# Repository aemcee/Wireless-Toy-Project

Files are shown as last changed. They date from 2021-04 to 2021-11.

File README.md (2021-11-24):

# Wireless-Toy-Project
ATmega328P based custom remote and unit (receiver) boards on arduino framework that will communicate over RF and with the following feature set: SD Card, RTC, Ultrasonic sensor, motor control, audio amplification w/audio jack or 8ohm speaker, motor control, LEDs

Remote PCB will replace current board in toy remote housing and receiver board will have custom 3D printed housing

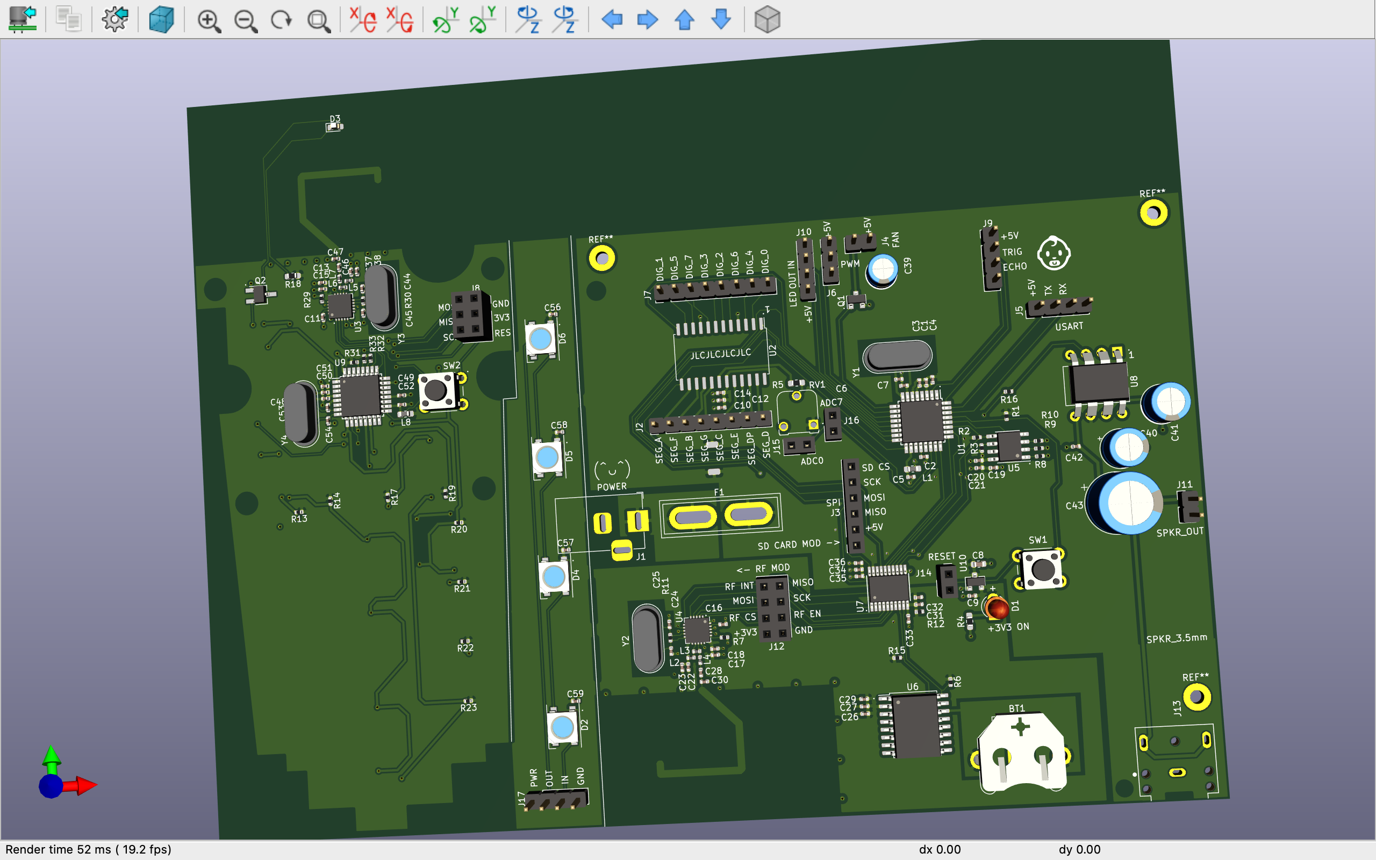
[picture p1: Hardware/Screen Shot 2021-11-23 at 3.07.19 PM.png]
name-of-you-image


Watch the video (https://youtu.be/jzv-52mN5sE)

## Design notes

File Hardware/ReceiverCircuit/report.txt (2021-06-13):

Info: Checking netlist symbol footprint “L1:/5F267CB6/5F404F19:Inductor_SMD:L_0603_1608Metric_Pad1.05x0.95mm_HandSolder”.
Info: Checking netlist symbol footprint “R4:/5F267E17/5F47181E:Resistor_SMD:R_0402_1005Metric”.
Info: Checking netlist symbol footprint “R3:/5F267CB6/5F282A2E:Resistor_SMD:R_0402_1005Metric”.
Info: Checking netlist symbol footprint “R2:/5F267CB6/5F283506:Resistor_SMD:R_0402_1005Metric”.
Info: Checking netlist symbol footprint “R1:/5F267CB6/5F312DFC:Resistor_SMD:R_0402_1005Metric”.
Info: Checking netlist symbol footprint “Q1:/5F26E841/5F41FD7E:Package_TO_SOT_SMD:SOT-23”.
Info: Checking netlist symbol footprint “L4:/5F26E841/5F33637F:Inductor_SMD:L_0402_1005Metric”.
Info: Checking netlist symbol footprint “L3:/5F26E841/5F33480A:Inductor_SMD:L_0402_1005Metric”.
Info: Checking netlist symbol footprint “L2:/5F26E841/5F337A25:Inductor_SMD:L_0402_1005Metric”.
Info: Checking netlist symbol footprint “R5:/5F26E841/5F3EAB85:Resistor_SMD:R_0603_1608Metric_Pad1.05x0.95mm_HandSolder”.
Info: Checking netlist symbol footprint “J7:/5F26E841/5F3A1FBF:Connector_PinHeader_2.54mm:PinHeader_1x04_P2.54mm_Vertical”.
Info: Checking netlist symbol footprint “J6:/5F30B967/5F3D61E1:Connector_PinHeader_2.54mm:PinHeader_1x03_P2.54mm_Vertical”.
Info: Checking netlist symbol footprint “J5:/5F30B967/5F3E867E:Connector_PinHeader_2.54mm:PinHeader_1x04_P2.54mm_Vertical”.
Info: Checking netlist symbol footprint “J4:/5F30B967/5F421C06:Connector_PinHeader_2.54mm:PinHeader_1x02_P2.54mm_Vertical”.
Info: Checking netlist symbol footprint “J3:/5F30B967/5F30DA44:Connector_PinHeader_2.54mm:PinHeader_1x03_P2.54mm_Vertical”.
Info: Checking netlist symbol footprint “J2:/5F30B967/5F30E60B:Connector_PinHeader_2.54mm:PinHeader_2x03_P2.54mm_Vertical”.
Info: Checking netlist symbol footprint “J1:/5F267E17/5F3750C2:Connector_BarrelJack:BarrelJack_Horizontal”.
Info: Checking netlist symbol footprint “F1:/5F267E17/5F26B922:Fuse:Fuse_Blade_ATO_directSolder”.
Info: Checking netlist symbol footprint “U1:/5F267CB6/5F27CF0E:Package_QFP:TQFP-32_7x7mm_P0.8mm”.
Info: Checking netlist symbol footprint “Y2:/5F26E841/5F3117DC:Crystal:Crystal_HC49-4H_Vertical”.
Info: Checking netlist symbol footprint “Y1:/5F267CB6/5F37F7A6:Crystal:Crystal_HC49-4H_Vertical”.
Info: Checking netlist symbol footprint “U10:/5F267E17/5F43C6FB:Package_TO_SOT_SMD:SOT-23”.
Info: Checking netlist symbol footprint “U7:/5F27C6CE/5F2CA946:Package_SO:TSSOP-20_4.4x6.5mm_P0.65mm”.
Info: Checking netlist symbol footprint “U6:/5F26E841/5F27713A:Package_SO:SOIC-16W_7.5x10.3mm_P1.27mm”.
Info: Checking netlist symbol footprint “U5:/5F26E841/5F26F784:Package_SO:SOIC-8_3.9x4.9mm_P1.27mm”.
Info: Checking netlist symbol footprint “U4:/5F26E841/5F279D2C:Package_DFN_QFN:QFN-20-1EP_4x4mm_P0.5mm_EP2.5x2.5mm”.
Info: Checking netlist symbol footprint “U2:/5F26E841/5F274BCB:Package_SO:SOP-24_7.5x15.4mm_P1.27mm”.
Info: Checking netlist symbol footprint “BT1:/5F26E841/5F2F7BE9:Battery:BatteryHolder_Keystone_3001_1x12mm”.
Info: Checking netlist symbol footprint “SW1:/5F267CB6/5F3116D4:Button_Switch_THT:SW_PUSH_6mm_H5mm”.
Info: Checking netlist symbol footprint “R12:/5F27C6CE/5F2F0D13:Resistor_SMD:R_0402_1005Metric”.
Info: Checking netlist symbol footprint “R11:/5F26E841/5F3167C4:Resistor_SMD:R_0402_1005Metric”.
Info: Checking netlist symbol footprint “R10:/5F26E841/5F261A38:Resistor_SMD:R_0402_1005Metric”.
Info: Checking netlist symbol footprint “R9:/5F26E841/5F262E96:Resistor_SMD:R_0402_1005Metric”.
Info: Checking netlist symbol footprint “R8:/5F26E841/5F263156:Resistor_SMD:R_0402_1005Metric”.
Info: Checking netlist symbol footprint “R7:/5F26E841/5F308377:Resistor_SMD:R_0402_1005Metric”.
Info: Checking netlist symbol footprint “R6:/5F27C6CE/5F3A68C5:Resistor_SMD:R_0402_1005Metric”.
Info: Checking netlist symbol footprint “C10:/5F26E841/5F3E017E:Capacitor_SMD:C_0402_1005Metric”.
Info: Checking netlist symbol footprint “C22:/5F26E841/5F3464D5:Capacitor_SMD:C_0402_1005Metric”.
Info: Checking netlist symbol footprint “C21:/5F26E841/5F28EC82:Capacitor_SMD:C_0402_1005Metric”.
Info: Checking netlist symbol footprint “C20:/5F26E841/5F28EC7B:Capacitor_SMD:C_0402_1005Metric”.
Info: Checking netlist symbol footprint “C19:/5F26E841/5F28EC74:Capacitor_SMD:C_0402_1005Metric”.
Info: Checking netlist symbol footprint “C18:/5F26E841/5F3017C4:Capacitor_SMD:C_0402_1005Metric”.
Info: Checking netlist symbol footprint “C17:/5F26E841/5F3017BD:Capacitor_SMD:C_0402_1005Metric”.
Info: Checking netlist symbol footprint “C16:/5F26E841/5F3AC90D:Capacitor_SMD:C_0402_1005Metric”.
Info: Checking netlist symbol footprint “C14:/5F26E841/5F3E018C:Capacitor_SMD:C_0402_1005Metric”.
Info: Checking netlist symbol footprint “C12:/5F26E841/5F3E0185:Capacitor_SMD:C_0402_1005Metric”.
Info: Checking netlist symbol footprint “D1:/5F267E17/5F470E62:”.
Info: Checking netlist symbol footprint “C9:/5F267E17/5F26B8F5:Capacitor_SMD:C_0402_1005Metric”.
Info: Checking netlist symbol footprint “C8:/5F267E17/5F26B8EF:Capacitor_SMD:C_0603_1608Metric”.
Info: Checking netlist symbol footprint “C7:/5F267CB6/5F381AE7:Capacitor_SMD:C_0402_1005Metric”.
Info: Checking netlist symbol footprint “C6:/5F267CB6/5F380939:Capacitor_SMD:C_0402_1005Metric”.
Info: Checking netlist symbol footprint “C5:/5F267CB6/5F40669F:Capacitor_SMD:C_0402_1005Metric”.
Info: Checking netlist symbol footprint “C4:/5F267CB6/5F27AAE0:Capacitor_SMD:C_0402_1005Metric”.
Info: Checking netlist symbol footprint “C3:/5F267CB6/5F27A7B7:Capacitor_SMD:C_0402_1005Metric”.
Info: Checking netlist symbol footprint “C2:/5F267CB6/5F314F9A:Capacitor_SMD:C_0402_1005Metric”.
Info: Checking netlist symbol footprint “C1:/5F267CB6/5F279DA3:Capacitor_SMD:C_0402_1005Metric”.
Info: Checking netlist symbol footprint “C24:/5F26E841/5F3199E1:Capacitor_SMD:C_0402_1005Metric”.
Info: Checking netlist symbol footprint “C36:/5F27C6CE/5F2CE47A:Capacitor_SMD:C_0402_1005Metric”.
Info: Checking netlist symbol footprint “C35:/5F27C6CE/5F2CE473:Capacitor_SMD:C_0402_1005Metric”.
Info: Checking netlist symbol footprint “C34:/5F27C6CE/5F2CE46C:Capacitor_SMD:C_0402_1005Metric”.
Info: Checking netlist symbol footprint “C33:/5F27C6CE/5F2CF71E:Capacitor_SMD:C_0402_1005Metric”.
Info: Checking netlist symbol footprint “C32:/5F27C6CE/5F2CF717:Capacitor_SMD:C_0402_1005Metric”.
Info: Checking netlist symbol footprint “C31:/5F27C6CE/5F2CF710:Capacitor_SMD:C_0402_1005Metric”.
Info: Checking netlist symbol footprint “C30:/5F26E841/5F340567:Capacitor_SMD:C_0402_1005Metric”.
Info: Checking netlist symbol footprint “C29:/5F26E841/5F2BBA88:Capacitor_SMD:C_0402_1005Metric”.
Info: Checking netlist symbol footprint “C28:/5F26E841/5F33F458:Capacitor_SMD:C_0402_1005Metric”.
Info: Checking netlist symbol footprint “C27:/5F26E841/5F2BBA81:Capacitor_SMD:C_0402_1005Metric”.
Info: Checking netlist symbol footprint “C26:/5F26E841/5F2BBA7A:Capacitor_SMD:C_0402_1005Metric”.
Info: Checking netlist symbol footprint “C25:/5F26E841/5F31BDA0:Capacitor_SMD:C_0402_1005Metric”.
Info: Checking netlist symbol footprint “C23:/5F26E841/5F3464DB:Capacitor_SMD:C_0402_1005Metric”.
Adding new symbol R10 footprint Resistor_SMD:R_0402_1005Metric.
Adding new symbol L2 footprint Inductor_SMD:L_0402_1005Metric.
Adding new symbol R9 footprint Resistor_SMD:R_0402_1005Metric.
Adding new symbol C30 footprint Capacitor_SMD:C_0402_1005Metric.
Adding new symbol R8 footprint Resistor_SMD:R_0402_1005Metric.
Adding new symbol L3 footprint Inductor_SMD:L_0402_1005Metric.
Adding new symbol L4 footprint Inductor_SMD:L_0402_1005Metric.
Adding new symbol Y1 footprint Crystal:Crystal_HC49-4H_Vertical.
Adding new symbol Y2 footprint Crystal:Crystal_HC49-4H_Vertical.
Error: Symbol J1 pad MP not found in footprint Connector_BarrelJack:BarrelJack_Horizontal.

Error: No footprint defined for symbol “D1”.

Error: Cannot add new symbol D1 due to missing footprint .

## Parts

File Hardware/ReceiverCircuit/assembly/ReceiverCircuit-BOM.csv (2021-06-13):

Comment | Designator | Footprint | LCSC
Battery_Cell | BT1 | Battery:BatteryHolder_Keystone_3001_1x12mm
.1u | C1,C2,C10,C19,C26,C31,C34,C42 | Capacitor_SMD:C_0402_1005Metric | C1525
33n | C16 | Capacitor_SMD:C_0402_1005Metric | C1585
10n | C17 | Capacitor_SMD:C_0402_1005Metric | C15195
1n | C18 | Capacitor_SMD:C_0402_1005Metric | C1523
2.2p | C22 | Capacitor_SMD:C_0402_1005Metric | C1559
4.7p | C23 | Capacitor_SMD:C_0402_1005Metric | C1569
1.5p | C28 | Capacitor_SMD:C_0402_1005Metric | C1552
.01u | C3,C12,C20,C27,C32,C35 | Capacitor_SMD:C_0402_1005Metric | C15195
1pF | C30 | Capacitor_SMD:C_0402_1005Metric | C1550
CP_Small | C39 | Capacitor_THT:CP_Radial_D5.0mm_P2.00mm
1u | C4,C9,C14,C21,C29,C33,C36 | Capacitor_SMD:C_0402_1005Metric | C52923
100u | C40,C41 | Capacitor_THT:CP_Radial_D6.3mm_P2.50mm
1000u | C43 | Capacitor_THT:CP_Radial_D10.0mm_P5.00mm
0.1u | C5 | Capacitor_SMD:C_0402_1005Metric | C1525
22p | C6,C7,C24,C25 | Capacitor_SMD:C_0402_1005Metric | C1555
10u | C8 | Capacitor_SMD:C_0603_1608Metric | C19702
LED_Small | D1 | LED_THT:LED_D3.0mm
2A | F1 | Fuse:Fuse_Blade_ATO_directSolder
Jack-DC | J1 | Connector_BarrelJack:BarrelJack_Horizontal
Conn_01x04_Male | J10 | Connector_PinHeader_2.54mm:PinHeader_1x04_P2.54mm_Vertical
Conn_02x04 | J12 | Connector_PinSocket_2.54mm:PinSocket_2x04_P2.54mm_Vertical
SJ1-3523N | J13 | ProjectFootprint:CUI_SJ1-3523N
Conn_01x02_Female | J14,J15,J16 | Connector_PinSocket_2.54mm:PinSocket_1x02_P2.54mm_Vertical
Conn_01x06_Female | J3 | Connector_PinSocket_2.54mm:PinSocket_1x06_P2.54mm_Vertical
Conn_01x02 | J4,J11 | Connector_PinHeader_2.54mm:PinHeader_1x02_P2.54mm_Vertical
Conn_01x04 | J5,J9 | Connector_PinHeader_2.54mm:PinHeader_1x04_P2.54mm_Vertical
Conn_01x03 | J6 | Connector_PinHeader_2.54mm:PinHeader_1x03_P2.54mm_Vertical
Conn_01x08 | J2,J7 | Connector_PinHeader_2.54mm:PinHeader_1x08_P2.54mm_Vertical
10u | L1 | Inductor_SMD:L_0603_1608Metric_Pad1.05x0.95mm_HandSolder
2.7n | L2 | Inductor_SMD:L_0402_1005Metric | C27123
8.2n | L3 | Inductor_SMD:L_0402_1005Metric | C16208
3.9n | L4 | Inductor_SMD:L_0402_1005Metric | C14033
Si2301CDS | Q1 | Package_TO_SOT_SMD:SOT-23 | C10487
10k | R1,R12 | Resistor_SMD:R_0402_1005Metric | C25744
1M | R11 | Resistor_SMD:R_0402_1005Metric | C26083
1k | R16 | Resistor_SMD:R_0402_1005Metric | C11702
4.7k | R2,R3,R6,R8,R9,R10,R15 | Resistor_SMD:R_0402_1005Metric | C25900
330 | R4 | Resistor_SMD:R_0603_1608Metric_Pad1.05x0.95mm_HandSolder
R_Small | R5 | Resistor_SMD:R_0603_1608Metric_Pad1.05x0.95mm_HandSolder
22k | R7 | Resistor_SMD:R_0402_1005Metric | C25768
R_POT_Small | RV1 | Potentiometer_THT:Potentiometer_Runtron_RM-065_Vertical
SW_Push | SW1 | Button_Switch_THT:SW_PUSH_6mm_H5mm
ATmega328P-AU | U1 | Package_QFP:TQFP-32_7x7mm_P0.8mm | C14877
TPS7A0533 | U10 | Package_TO_SOT_SMD:SOT-23
MAX7219 | U2 | Package_SO:SOP-24_7.5x15.4mm_P1.27mm
nRF24L01P | U4 | Package_DFN_QFN:QFN-20-1EP_4x4mm_P0.5mm_EP2.5x2.5mm | C8791
AT24C256C-SSHL-T | U5 | Package_SO:SOIC-8_3.9x4.9mm_P1.27mm | C6482
DS3231M | U6 | Package_SO:SOIC-16W_7.5x10.3mm_P1.27mm | C37663
TXS0108EPW | U7 | Package_SO:TSSOP-20_4.4x6.5mm_P0.65mm | C17206
LM386 | U8 | Package_DIP:DIP-8_W10.16mm
16MHz | Y1,Y2 | Crystal:Crystal_HC49-4H_Vertical

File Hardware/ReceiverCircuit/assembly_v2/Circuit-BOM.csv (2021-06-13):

Comment | Designator | Footprint | LCSC
Battery_Cell | BT1 | Battery:BatteryHolder_Keystone_3001_1x12mm
.1u | C1,C2,C10,C19,C26,C31,C34,C42,C48,C49 | Capacitor_SMD:C_0402_1005Metric | C1525
33n | C11,C16 | Capacitor_SMD:C_0402_1005Metric | C1585
10n | C13,C17 | Capacitor_SMD:C_0402_1005Metric | C15195
1n | C15,C18 | Capacitor_SMD:C_0402_1005Metric | C1523
2.2p | C22,C37 | Capacitor_SMD:C_0402_1005Metric | C1559
4.7p | C23,C38 | Capacitor_SMD:C_0402_1005Metric | C1569
1.5p | C28,C46 | Capacitor_SMD:C_0402_1005Metric | C1552
.01u | C3,C12,C20,C27,C32,C35,C50,C56,C57,C58,C59 | Capacitor_SMD:C_0402_1005Metric | C15195
1pF | C30,C47 | Capacitor_SMD:C_0402_1005Metric | C1550
CP_Small | C39 | Capacitor_THT:CP_Radial_D5.0mm_P2.00mm
1u | C4,C9,C14,C21,C29,C33,C36,C51 | Capacitor_SMD:C_0402_1005Metric | C52923
100u | C40,C41 | Capacitor_THT:CP_Radial_D6.3mm_P2.50mm
1000u | C43 | Capacitor_THT:CP_Radial_D10.0mm_P5.00mm
0.1u | C5,C52 | Capacitor_SMD:C_0402_1005Metric | C1525
22p | C6,C7,C24,C25,C44,C45,C53,C54 | Capacitor_SMD:C_0402_1005Metric | C1555
10u | C8 | Capacitor_SMD:C_0603_1608Metric | C19702
LED_Small | D1 | LED_THT:LED_D3.0mm
WS2812B | D2,D4,D5,D6 | LED_SMD:LED_WS2812B_PLCC4_5.0x5.0mm_P3.2mm
LED | D3 | LED_SMD:LED_0603_1608Metric_Pad1.05x0.95mm_HandSolder
2A | F1 | Fuse:Fuse_Blade_ATO_directSolder
Jack-DC | J1 | Connector_BarrelJack:BarrelJack_Horizontal
Conn_01x04_Male | J10,J17 | Connector_PinHeader_2.54mm:PinHeader_1x04_P2.54mm_Vertical
Conn_02x04 | J12 | Connector_PinSocket_2.54mm:PinSocket_2x04_P2.54mm_Vertical
SJ1-3523N | J13 | ProjectFootprint:CUI_SJ1-3523N
Conn_01x02_Female | J14,J15,J16 | Connector_PinSocket_2.54mm:PinSocket_1x02_P2.54mm_Vertical
Conn_01x06_Female | J3 | Connector_PinSocket_2.54mm:PinSocket_1x06_P2.54mm_Vertical
Conn_01x02 | J4,J11 | Connector_PinHeader_2.54mm:PinHeader_1x02_P2.54mm_Vertical
Conn_01x04 | J5,J9 | Connector_PinHeader_2.54mm:PinHeader_1x04_P2.54mm_Vertical
Conn_01x03 | J6 | Connector_PinHeader_2.54mm:PinHeader_1x03_P2.54mm_Vertical
Conn_01x08 | J2,J7 | Connector_PinHeader_2.54mm:PinHeader_1x08_P2.54mm_Vertical
Conn_02x03_Odd_Even | J8 | Connector_PinSocket_2.54mm:PinSocket_2x03_P2.54mm_Vertical
10u | L1,L8 | Inductor_SMD:L_0603_1608Metric_Pad1.05x0.95mm_HandSolder
2.7n | L2,L5 | Inductor_SMD:L_0402_1005Metric | C27123
8.2n | L3,L6 | Inductor_SMD:L_0402_1005Metric | C16208
3.9n | L4,L7 | Inductor_SMD:L_0402_1005Metric | C14033
Si2301CDS | Q1 | Package_TO_SOT_SMD:SOT-23 | C10487
2N3904 | Q2 | Package_TO_SOT_SMD:SOT-23W_Handsoldering
10k | R1,R12,R13,R14,R17,R19,R20,R21,R22,R23,R31 | Resistor_SMD:R_0402_1005Metric | C25744
1M | R11,R30 | Resistor_SMD:R_0402_1005Metric | C26083
1k | R16 | Resistor_SMD:R_0402_1005Metric | C11702
4.7k | R2,R3,R6,R8,R9,R10,R15,R32,R33 | Resistor_SMD:R_0402_1005Metric | C25900
330 | R4,R18 | Resistor_SMD:R_0603_1608Metric_Pad1.05x0.95mm_HandSolder
R_Small | R5 | Resistor_SMD:R_0603_1608Metric_Pad1.05x0.95mm_HandSolder
22k | R7,R29 | Resistor_SMD:R_0402_1005Metric | C25768
R_POT_Small | RV1 | Potentiometer_THT:Potentiometer_Runtron_RM-065_Vertical
SW_Push | SW1,SW2 | Button_Switch_THT:SW_PUSH_6mm_H5mm
SW_Push2 | SW_0,SW_1,SW_2,SW_3,SW_4,SW_5,SW_6,SW_7,SW_8,SW_9,SW_10,SW_11,SW_12,SW_13 | LogoSilkscreen:Button_Test2
ATmega328P-AU | U1,U9 | Package_QFP:TQFP-32_7x7mm_P0.8mm | C14877
TPS7A0533 | U10 | Package_TO_SOT_SMD:SOT-23
MAX7219 | U2 | Package_SO:SOP-24_7.5x15.4mm_P1.27mm
nRF24L01P | U3,U4 | Package_DFN_QFN:QFN-20-1EP_4x4mm_P0.5mm_EP2.5x2.5mm | C8791
AT24C256C-SSHL-T | U5 | Package_SO:SOIC-8_3.9x4.9mm_P1.27mm | C6482
DS3231M | U6 | Package_SO:SOIC-16W_7.5x10.3mm_P1.27mm | C37663
TXS0108EPW | U7 | Package_SO:TSSOP-20_4.4x6.5mm_P0.65mm | C17206
LM386 | U8 | Package_DIP:DIP-8_W10.16mm
16MHz | Y1,Y2,Y3,Y4 | Crystal:Crystal_HC49-4H_Vertical

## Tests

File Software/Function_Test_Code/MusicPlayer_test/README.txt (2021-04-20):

Creating audio file to play
Convert audio file to wav file using: https://audio.online-convert.com/convert-to-wav
Use wav file settings found here: https://circuitdigest.com/microcontroller-projects/arduino-audio-music-player

SD card setup
Setup using a class 10 4GB SD Card and formatted as FAT32 
Connect SD Card module to SPI pin header on unitduino

Tested with 
* 8 Ohm speaker connected directly to J11 Spkr_out
* earbuds connected to J13

Update pcmConfig.h file
uncomment the following 
#define DISABLE_SPEAKER2 (optional) extra precaution since using pin 10 as SD chip select
#define USE_TIMER2

Update sketch ino file
Set SD_ChipSelectPin to 10
Set speakerPin to 3

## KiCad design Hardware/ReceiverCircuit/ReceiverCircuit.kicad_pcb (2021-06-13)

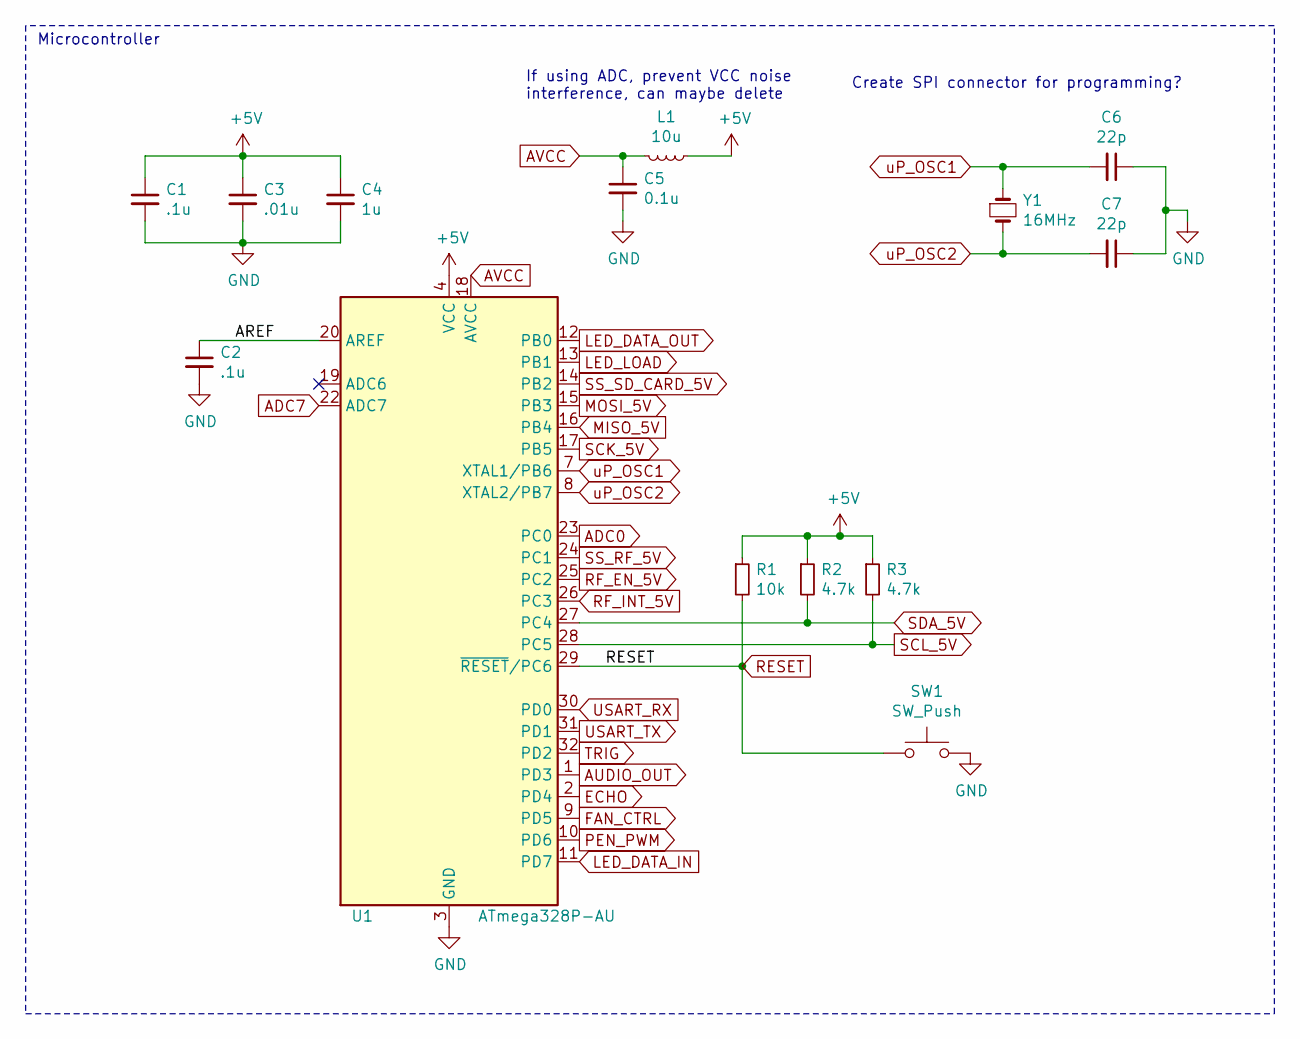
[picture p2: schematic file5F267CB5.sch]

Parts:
C1, C2: .1u; C_0402_1005Metric; Part Number CL05B104KO5NNNC; LCSC Part # C1525
C3: .01u; C_0402_1005Metric; Part Number CL05B103KB5NNNC; LCSC Part # C15195
C4: 1u; C_0402_1005Metric; Part Number CL05A105KA5NQNC; LCSC Part # C52923
C5: 0.1u; C_0402_1005Metric; Part Number CL05B104KO5NNNC; LCSC Part # C1525
C6, C7: 22p; C_0402_1005Metric; Part Number 0402CG220J500NT; LCSC Part # C1555
L1: 10u; L_0603_1608Metric_Pad1.05x0.95mm_HandSolder
R1: 10k; R_0402_1005Metric; Part Number 0402WGF1002TCE; LCSC Part # C25744
R2, R3: 4.7k; R_0402_1005Metric; Part Number 0402WGF4701TCE; LCSC Part # C25900
SW1: SW_Push; SW_PUSH_6mm_H5mm
U1: ATmega328P-AU; TQFP-32_7x7mm_P0.8mm; Part Number ATMEGA328P-AU; LCSC C14877
Y1: 16MHz; Crystal_HC49-4H_Vertical

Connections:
/Microcontroller/AREF: C2.1, U1.20 (AREF)
ADC0: U1.23 (PC0); also elsewhere on the board
ADC7: U1.22 (ADC7); also elsewhere on the board
AUDIO_OUT: U1.1 (PD3); also elsewhere on the board
AVCC: C5.1, L1.2, U1.18 (AVCC)
ECHO: U1.2 (PD4); also elsewhere on the board
FAN_CTRL: U1.9 (PD5); also elsewhere on the board
FAN_PWR: C1.1, C3.1, C4.1, L1.1, R1.1, R2.1, R3.1, U1.4 (VCC), U1.6 (VCC); also elsewhere on the board
GND: C1.2, C2.2, C3.2, C4.2, C5.2, C6.1, C7.1, SW1.2, U1.3 (GND), U1.5 (GND), U1.21 (GND); also elsewhere on the board
LED_DATA_IN: U1.11 (PD7); also elsewhere on the board
LED_DATA_OUT: U1.12 (PB0); also elsewhere on the board
LED_LOAD: U1.13 (PB1); also elsewhere on the board
MISO_5V: U1.16 (PB4); also elsewhere on the board
MOSI_5V: U1.15 (PB3); also elsewhere on the board
PEN_PWM: U1.10 (PD6); also elsewhere on the board
RESET: R1.2, SW1.1, U1.29 (~RESET~/PC6); also elsewhere on the board
RF_EN_5V: U1.25 (PC2); also elsewhere on the board
RF_INT_5V: U1.26 (PC3); also elsewhere on the board
SCK_5V: U1.17 (PB5); also elsewhere on the board
SCL_5V: R3.2, U1.28 (PC5); also elsewhere on the board
SDA_5V: R2.2, U1.27 (PC4); also elsewhere on the board
SS_RF_5V: U1.24 (PC1); also elsewhere on the board
SS_SD_CARD_5V: U1.14 (PB2); also elsewhere on the board
TRIG: U1.32 (PD2); also elsewhere on the board
USART_RX: U1.30 (PD0); also elsewhere on the board
USART_TX: U1.31 (PD1); also elsewhere on the board
uP_OSC1: C6.2, U1.7 (XTAL1/PB6), Y1.1
uP_OSC2: C7.2, U1.8 (XTAL2/PB7), Y1.2

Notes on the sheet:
If using ADC, prevent VCC noise interference, can maybe delete
Create SPI connector for programming?
Microcontroller

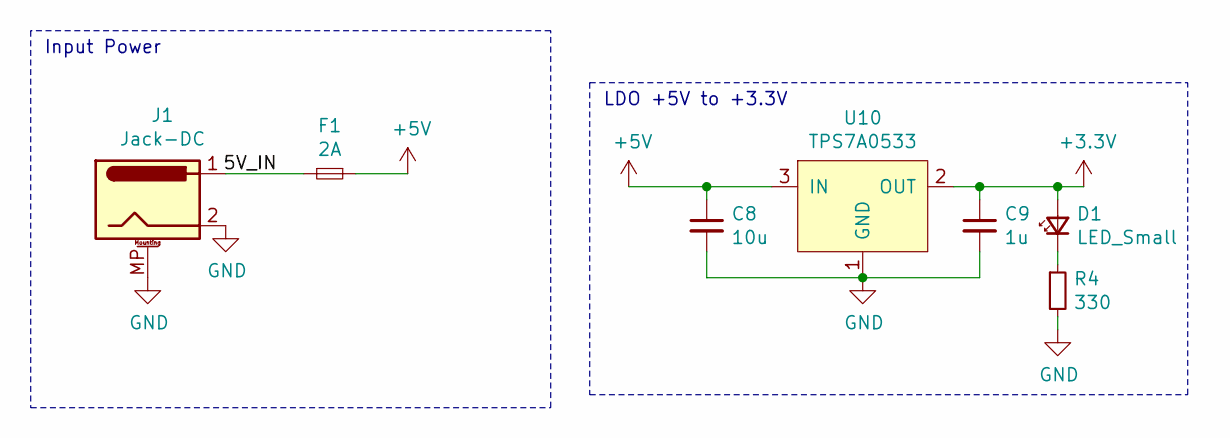
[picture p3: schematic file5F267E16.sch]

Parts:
C8: 10u; C_0603_1608Metric; Part Number CL10A106KP8NNNC; LCSC Part # C19702
C9: 1u; C_0402_1005Metric; Part Number CL05A105KA5NQNC; LCSC Part # C52923
D1: LED_Small; LED_D3.0mm
F1: 2A; Fuse_Blade_ATO_directSolder
J1: Jack-DC; BarrelJack_Horizontal
R4: 330; R_0603_1608Metric_Pad1.05x0.95mm_HandSolder
U10: TPS7A0533; SOT-23

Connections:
+3V3: C9.1, D1.2 (A), U10.2 (OUT); also elsewhere on the board
/Power/5V_IN: F1.1, J1.1
FAN_PWR: C8.1, F1.2, U10.3 (IN); also elsewhere on the board
GND: C8.2, C9.2, J1.2, J1.MP (MountPin), R4.2, U10.1 (GND); also elsewhere on the board
unnamed: D1.1 (K), R4.1

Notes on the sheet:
Input Power
LDO +5V to +3.3V

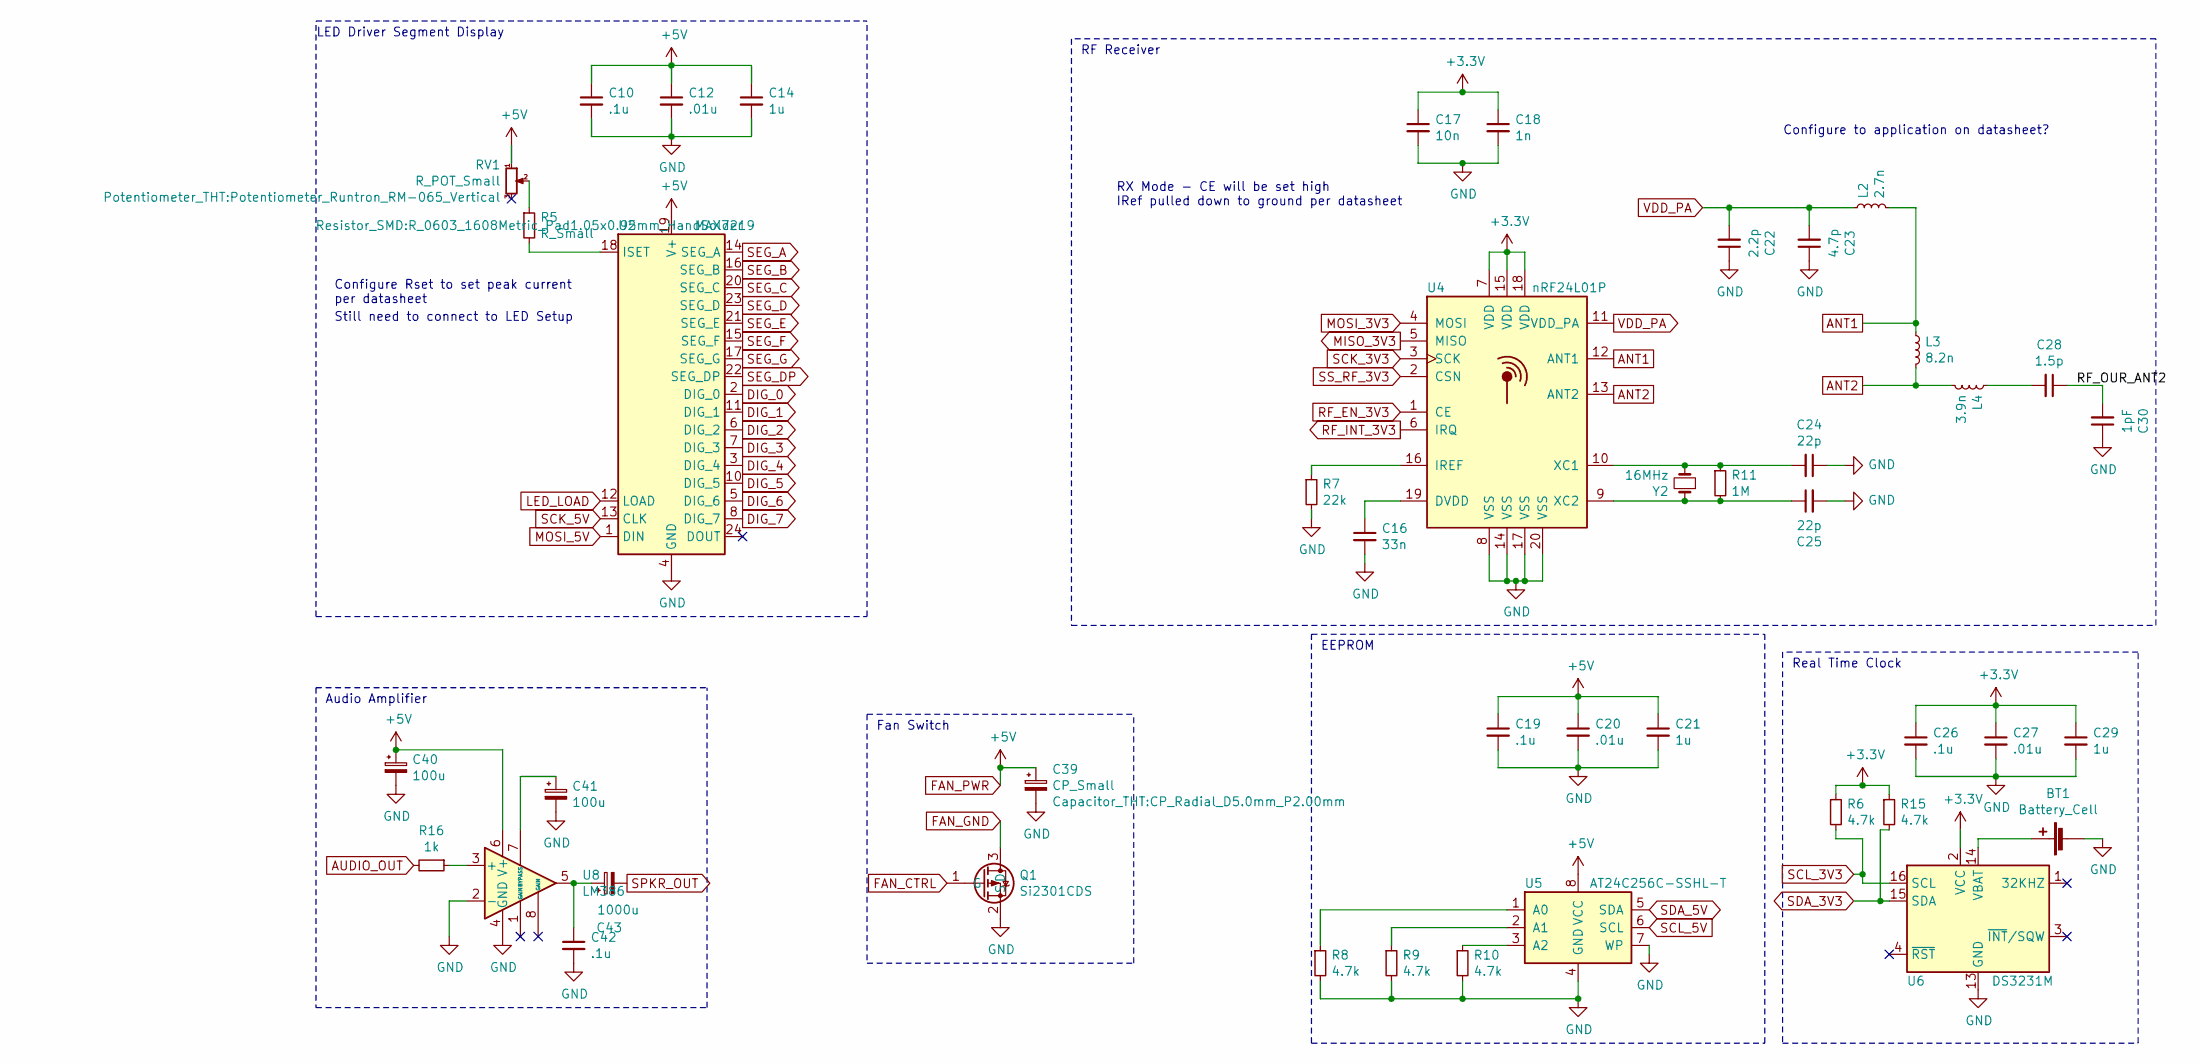
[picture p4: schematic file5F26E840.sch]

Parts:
BT1: Battery_Cell; BatteryHolder_Keystone_3001_1x12mm
C10, C19, C26, C42: .1u; C_0402_1005Metric; Part Number CL05B104KO5NNNC; LCSC Part # C1525
C12, C20, C27: .01u; C_0402_1005Metric; Part Number CL05B103KB5NNNC; LCSC Part # C15195
C14, C21, C29: 1u; C_0402_1005Metric; Part Number CL05A105KA5NQNC; LCSC Part # C52923
C16: 33n; C_0402_1005Metric; Part Number 0402F333M500NT; LCSC Part # C1585
C17: 10n; C_0402_1005Metric; Part Number CL05B103KB5NNNC; LCSC Part # C15195
C18: 1n; C_0402_1005Metric; Part Number 0402B102K500NT; LCSC Part # C1523
C22: 2.2p; C_0402_1005Metric; Part Number 0402CG2R2C500NT; LCSC Part # C1559
C23: 4.7p; C_0402_1005Metric; Part Number 0402CG4R7C500NT; LCSC Part # C1569
C24, C25: 22p; C_0402_1005Metric; Part Number 0402CG220J500NT; LCSC Part # C1555
C28: 1.5p; C_0402_1005Metric; Part Number 0402CG1R5C500NT; LCSC Part # C1552
C30: 1pF; C_0402_1005Metric; Part Number 0402CG1R0C500NT; LCSC Part # C1550
C39: CP_Small; CP_Radial_D5.0mm_P2.00mm
C40, C41: 100u; CP_Radial_D6.3mm_P2.50mm
C43: 1000u; CP_Radial_D10.0mm_P5.00mm
L2: 2.7n; L_0402_1005Metric; Part Number SDCL1005C2N7STDF; LCSC Part # C27123
L3: 8.2n; L_0402_1005Metric; Part Number SDCL1005C8N2JTDF; LCSC Part # C16208
L4: 3.9n; L_0402_1005Metric; Part Number SDCL1005C3N9STDF; LCSC Part # C14033
Q1: Si2301CDS; SOT-23; Part Number SI2301CDS-T1-GE3; LCSC Part # C10487
R5: R_Small; R_0603_1608Metric_Pad1.05x0.95mm_HandSolder
R6, R8, R9, R10, R15: 4.7k; R_0402_1005Metric; Part Number 0402WGF4701TCE; LCSC Part # C25900
R7: 22k; R_0402_1005Metric; Part Number 0402WGF2202TCE; LCSC Part # C25768
R11: 1M; R_0402_1005Metric; Part Number 0402WGF1004TCE; LCSC Part # C26083
R16: 1k; R_0402_1005Metric; Part Number 0402WGF1001TCE; LCSC Part # C11702
RV1: R_POT_Small; Potentiometer_Runtron_RM-065_Vertical
U2: MAX7219; SOP-24_7.5x15.4mm_P1.27mm
U4: nRF24L01P; QFN-20-1EP_4x4mm_P0.5mm_EP2.5x2.5mm; Part Number NRF24L01P-R; LCSC Part # C8791
U5: AT24C256C-SSHL-T; SOIC-8_3.9x4.9mm_P1.27mm; Part Number AT24C256C-SSHL-T; LCSC Part # C6482
U6: DS3231M; SOIC-16W_7.5x10.3mm_P1.27mm; Part Number DS3231M+TRL; LCSC Part # C37663
U8: LM386; DIP-8_W10.16mm
Y2: 16MHz; Crystal_HC49-4H_Vertical

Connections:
+3V3: C17.1, C18.1, C26.1, C27.1, C29.1, R6.1, R15.1, U4.7 (VDD), U4.15 (VDD), U4.18 (VDD), U6.2 (VCC); also elsewhere on the board
/Support ICs/RF_OUR_ANT2: C28.1, C30.2
ANT1: L2.2, L3.1, U4.12 (ANT1)
ANT2: L3.2, L4.2, U4.13 (ANT2)
AUDIO_OUT: R16.2; also elsewhere on the board
DIG_0: U2.2 (DIG_0); also elsewhere on the board
DIG_1: U2.11 (DIG_1); also elsewhere on the board
DIG_2: U2.6 (DIG_2); also elsewhere on the board
DIG_3: U2.7 (DIG_3); also elsewhere on the board
DIG_4: U2.3 (DIG_4); also elsewhere on the board
DIG_5: U2.10 (DIG_5); also elsewhere on the board
DIG_6: U2.5 (DIG_6); also elsewhere on the board
DIG_7: U2.8 (DIG_7); also elsewhere on the board
FAN_CTRL: Q1.1 (G); also elsewhere on the board
FAN_GND: Q1.3 (D); also elsewhere on the board
FAN_PWR: C10.1, C12.1, C14.1, C19.1, C20.1, C21.1, C39.1, C40.1, RV1.1, U2.19 (V+), U5.8 (VCC), U8.6 (V+); also elsewhere on the board
GND: BT1.2 (-), C10.2, C12.2, C14.2, C16.2, C17.2, C18.2, C19.2, C20.2, C21.2, C22.1, C23.1, C24.1, C25.2, C26.2, C27.2, C29.2, C30.1, C39.2, C40.2, C41.2, C42.2, Q1.2 (S), R7.2, R8.2, R9.2, R10.2, U2.4 (GND), U2.9 (GND), U4.8 (VSS), U4.14 (VSS), U4.17 (VSS), U4.20 (VSS), U5.4 (GND), U5.7 (WP), U6.5 (GND), U6.6 (GND), U6.7 (GND), U6.8 (GND), U6.9 (GND), U6.10 (GND), U6.11 (GND), U6.12 (GND), U6.13 (GND), U8.2 (-), U8.4 (GND); also elsewhere on the board
LED_LOAD: U2.12 (LOAD); also elsewhere on the board
MISO_3V3: U4.5 (MISO); also elsewhere on the board
MOSI_3V3: U4.4 (MOSI); also elsewhere on the board
MOSI_5V: U2.1 (DIN); also elsewhere on the board
unnamed: BT1.1 (+), U6.14 (VBAT)
unnamed: C16.1, U4.19 (DVDD)
unnamed: C24.2, R11.1, U4.10 (XC1), Y2.2
unnamed: C25.1, R11.2, U4.9 (XC2), Y2.1
unnamed: C28.2, L4.1
unnamed: C41.1, U8.7 (BYPASS)
unnamed: C42.1, C43.1, U8.5
unnamed: R5.1, RV1.2
unnamed: R5.2, U2.18 (ISET)
unnamed: R7.1, U4.16 (IREF)
unnamed: R8.1, U5.1 (A0)
unnamed: R9.1, U5.2 (A1)
unnamed: R10.1, U5.3 (A2)
unnamed: R16.1, U8.3 (+)
RF_EN_3V3: U4.1 (CE); also elsewhere on the board
RF_INT_3V3: U4.6 (IRQ); also elsewhere on the board
SCK_3V3: U4.3 (SCK); also elsewhere on the board
SCK_5V: U2.13 (CLK); also elsewhere on the board
SCL_3V3: R6.2, U6.16 (SCL); also elsewhere on the board
SCL_5V: U5.6 (SCL); also elsewhere on the board
SDA_3V3: R15.2, U6.15 (SDA); also elsewhere on the board
SDA_5V: U5.5 (SDA); also elsewhere on the board
SEG_A: U2.14 (SEG_A); also elsewhere on the board
SEG_B: U2.16 (SEG_B); also elsewhere on the board
SEG_C: U2.20 (SEG_C); also elsewhere on the board
SEG_D: U2.23 (SEG_D); also elsewhere on the board
SEG_DP: U2.22 (SEG_DP); also elsewhere on the board
SEG_E: U2.21 (SEG_E); also elsewhere on the board
SEG_F: U2.15 (SEG_F); also elsewhere on the board
SEG_G: U2.17 (SEG_G); also elsewhere on the board
SPKR_OUT: C43.2; also elsewhere on the board
SS_RF_3V3: U4.2 (CSN); also elsewhere on the board
VDD_PA: C22.2, C23.2, L2.1, U4.11 (VDD_PA)

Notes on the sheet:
RX Mode - CE will be set high IRef pulled down to ground per datasheet
Configure Rset to set peak current per datasheet
Still need to connect to LED Setup
EEPROM
Real Time Clock
LED Driver Segment Display
RF Receiver
Configure to application on datasheet?
Fan Switch
Audio Amplifier

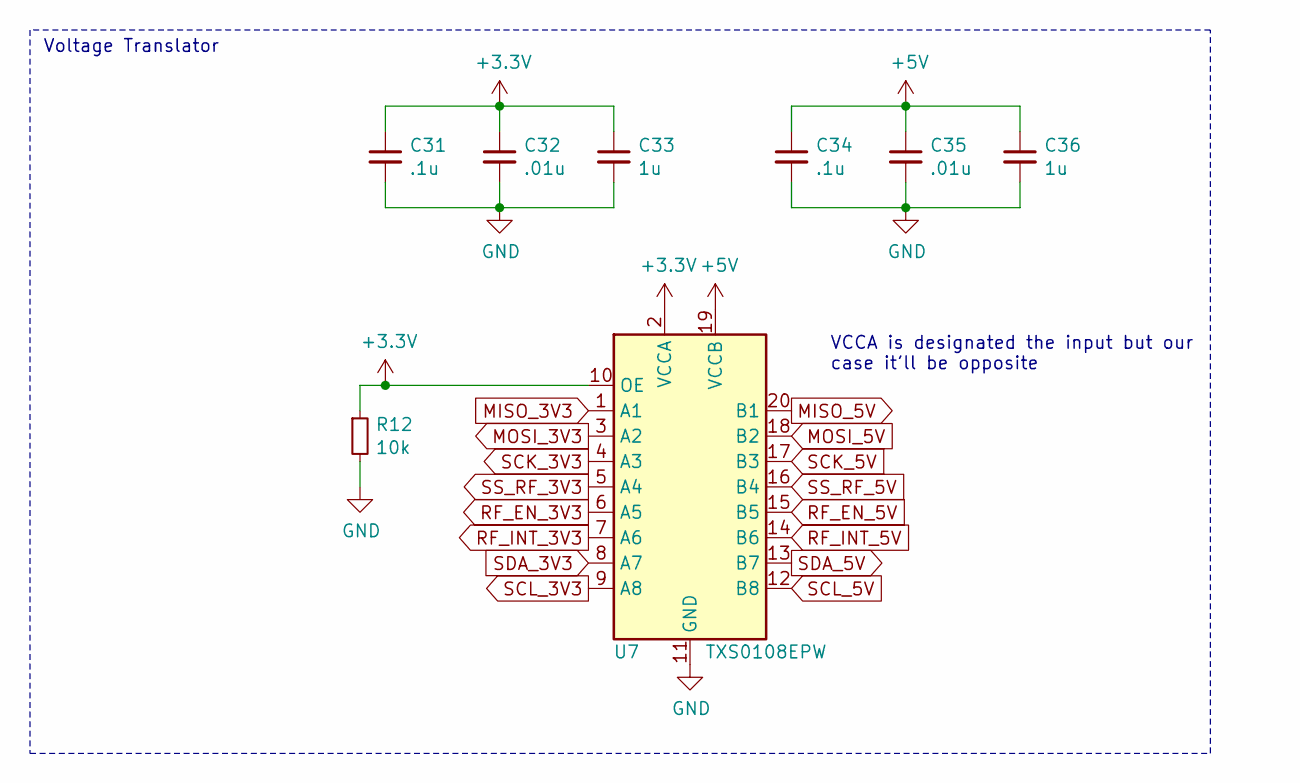
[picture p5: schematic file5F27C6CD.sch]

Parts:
C31, C34: .1u; C_0402_1005Metric; Part Number CL05B104KO5NNNC; LCSC Part # C1525
C32, C35: .01u; C_0402_1005Metric; Part Number CL05B103KB5NNNC; LCSC Part # C15195
C33, C36: 1u; C_0402_1005Metric; Part Number CL05A105KA5NQNC; LCSC Part # C52923
R12: 10k; R_0402_1005Metric; Part Number 0402WGF1002TCE; LCSC Part # C25744
U7: TXS0108EPW; TSSOP-20_4.4x6.5mm_P0.65mm; Part Number TXS0108EPWR; LCSC Part # C17206

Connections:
+3V3: C31.1, C32.1, C33.1, R12.1, U7.2 (VCCA), U7.10 (OE); also elsewhere on the board
FAN_PWR: C34.1, C35.1, C36.1, U7.19 (VCCB); also elsewhere on the board
GND: C31.2, C32.2, C33.2, C34.2, C35.2, C36.2, R12.2, U7.11 (GND); also elsewhere on the board
MISO_3V3: U7.1 (A1); also elsewhere on the board
MISO_5V: U7.20 (B1); also elsewhere on the board
MOSI_3V3: U7.3 (A2); also elsewhere on the board
MOSI_5V: U7.18 (B2); also elsewhere on the board
RF_EN_3V3: U7.6 (A5); also elsewhere on the board
RF_EN_5V: U7.15 (B5); also elsewhere on the board
RF_INT_3V3: U7.7 (A6); also elsewhere on the board
RF_INT_5V: U7.14 (B6); also elsewhere on the board
SCK_3V3: U7.4 (A3); also elsewhere on the board
SCK_5V: U7.17 (B3); also elsewhere on the board
SCL_3V3: U7.9 (A8); also elsewhere on the board
SCL_5V: U7.12 (B8); also elsewhere on the board
SDA_3V3: U7.8 (A7); also elsewhere on the board
SDA_5V: U7.13 (B7); also elsewhere on the board
SS_RF_3V3: U7.5 (A4); also elsewhere on the board
SS_RF_5V: U7.16 (B4); also elsewhere on the board

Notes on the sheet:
VCCA is designated the input but our case it'll be opposite
Voltage Translator

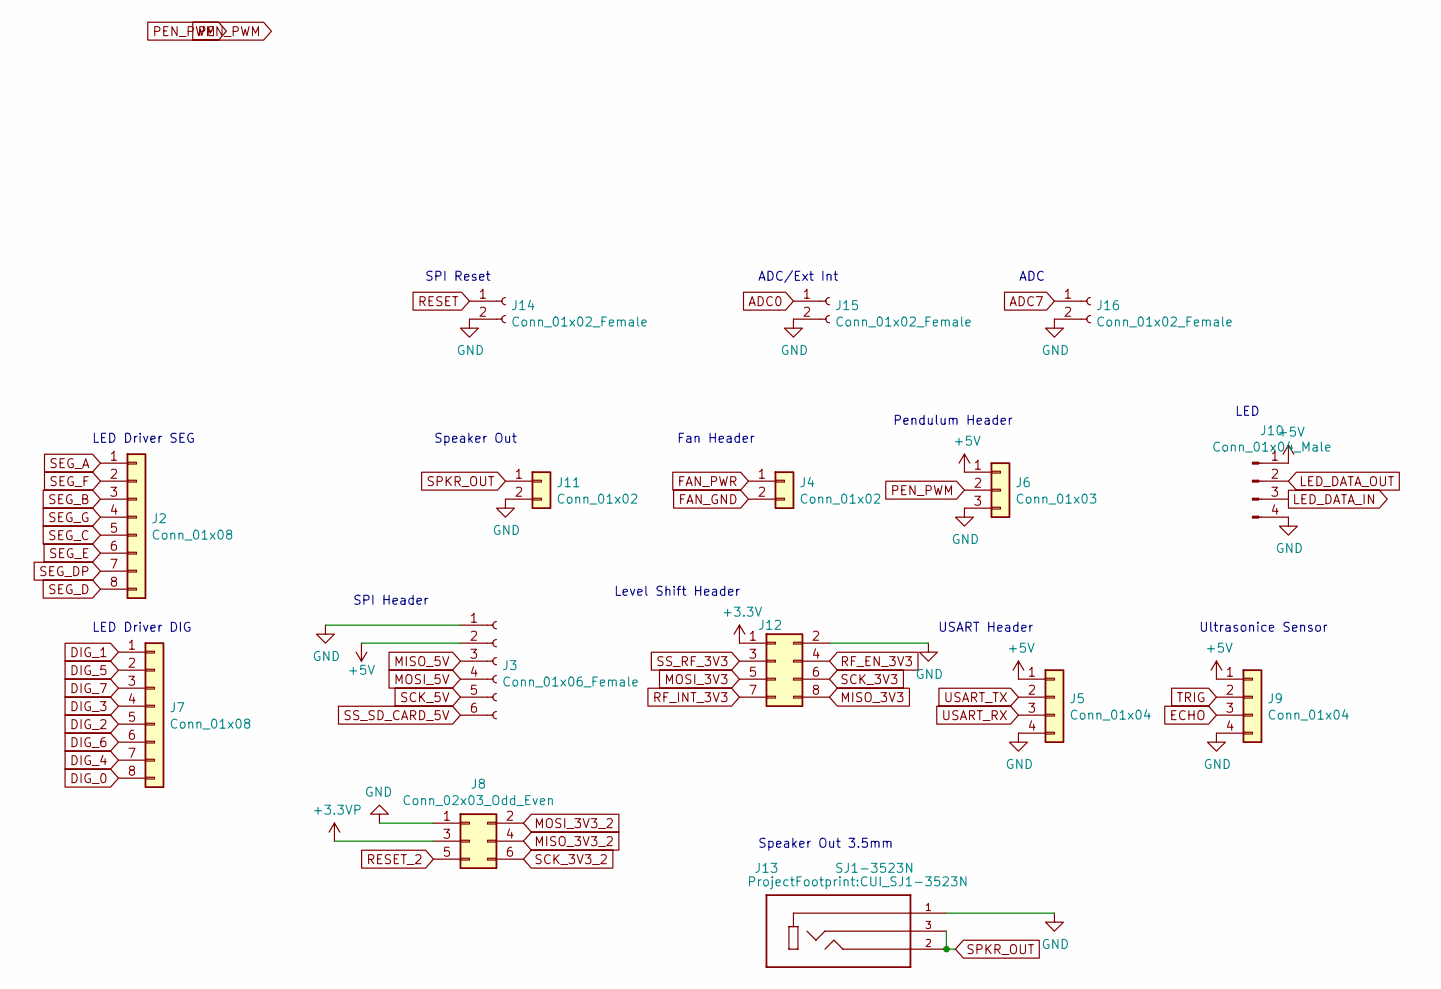
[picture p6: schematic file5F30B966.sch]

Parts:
J2, J7: Conn_01x08; PinHeader_1x08_P2.54mm_Vertical
J3: Conn_01x06_Female; PinSocket_1x06_P2.54mm_Vertical
J4, J11: Conn_01x02; PinHeader_1x02_P2.54mm_Vertical
J5, J9: Conn_01x04; PinHeader_1x04_P2.54mm_Vertical
J6: Conn_01x03; PinHeader_1x03_P2.54mm_Vertical
J8: Conn_02x03_Odd_Even; PinSocket_2x03_P2.54mm_Vertical
J10: Conn_01x04_Male; PinHeader_1x04_P2.54mm_Vertical
J12: Conn_02x04; PinSocket_2x04_P2.54mm_Vertical
J13: SJ1-3523N; CUI_SJ1-3523N
J14, J15, J16: Conn_01x02_Female; PinSocket_1x02_P2.54mm_Vertical

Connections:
+3.3VP: J8.3; also elsewhere on the board
+3V3: J12.1; also elsewhere on the board
ADC0: J15.1; also elsewhere on the board
ADC7: J16.1; also elsewhere on the board
DIG_0: J7.8; also elsewhere on the board
DIG_1: J7.1; also elsewhere on the board
DIG_2: J7.5; also elsewhere on the board
DIG_3: J7.4; also elsewhere on the board
DIG_4: J7.7; also elsewhere on the board
DIG_5: J7.2; also elsewhere on the board
DIG_6: J7.6; also elsewhere on the board
DIG_7: J7.3; also elsewhere on the board
ECHO: J9.3; also elsewhere on the board
FAN_GND: J4.2; also elsewhere on the board
FAN_PWR: J3.2, J4.1, J5.1, J6.1, J9.1, J10.1; also elsewhere on the board
GND: J3.1, J5.4, J6.3, J8.1, J9.4, J10.4, J11.2, J12.2, J13.1, J14.2, J15.2, J16.2; also elsewhere on the board
LED_DATA_IN: J10.3; also elsewhere on the board
LED_DATA_OUT: J10.2; also elsewhere on the board
MISO_3V3: J12.8; also elsewhere on the board
MISO_3V3_2: J8.4; also elsewhere on the board
MISO_5V: J3.3; also elsewhere on the board
MOSI_3V3: J12.5; also elsewhere on the board
MOSI_3V3_2: J8.2; also elsewhere on the board
MOSI_5V: J3.4; also elsewhere on the board
PEN_PWM: J6.2; also elsewhere on the board
RESET: J14.1; also elsewhere on the board
RESET_2: J8.5; also elsewhere on the board
RF_EN_3V3: J12.4; also elsewhere on the board
RF_INT_3V3: J12.7; also elsewhere on the board
SCK_3V3: J12.6; also elsewhere on the board
SCK_3V3_2: J8.6; also elsewhere on the board
SCK_5V: J3.5; also elsewhere on the board
SEG_A: J2.1; also elsewhere on the board
SEG_B: J2.3; also elsewhere on the board
SEG_C: J2.5; also elsewhere on the board
SEG_D: J2.8; also elsewhere on the board
SEG_DP: J2.7; also elsewhere on the board
SEG_E: J2.6; also elsewhere on the board
SEG_F: J2.2; also elsewhere on the board
SEG_G: J2.4; also elsewhere on the board
SPKR_OUT: J11.1, J13.2, J13.3; also elsewhere on the board
SS_RF_3V3: J12.3; also elsewhere on the board
SS_SD_CARD_5V: J3.6; also elsewhere on the board
TRIG: J9.2; also elsewhere on the board
USART_RX: J5.3; also elsewhere on the board
USART_TX: J5.2; also elsewhere on the board

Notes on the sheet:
Fan Header
Pendulum Header
USART Header
Ultrasonice Sensor
LED Driver SEG
LED Driver DIG
SPI Header
Level Shift Header
Speaker Out
Speaker Out 3.5mm
SPI Reset
ADC/Ext Int
ADC
LED

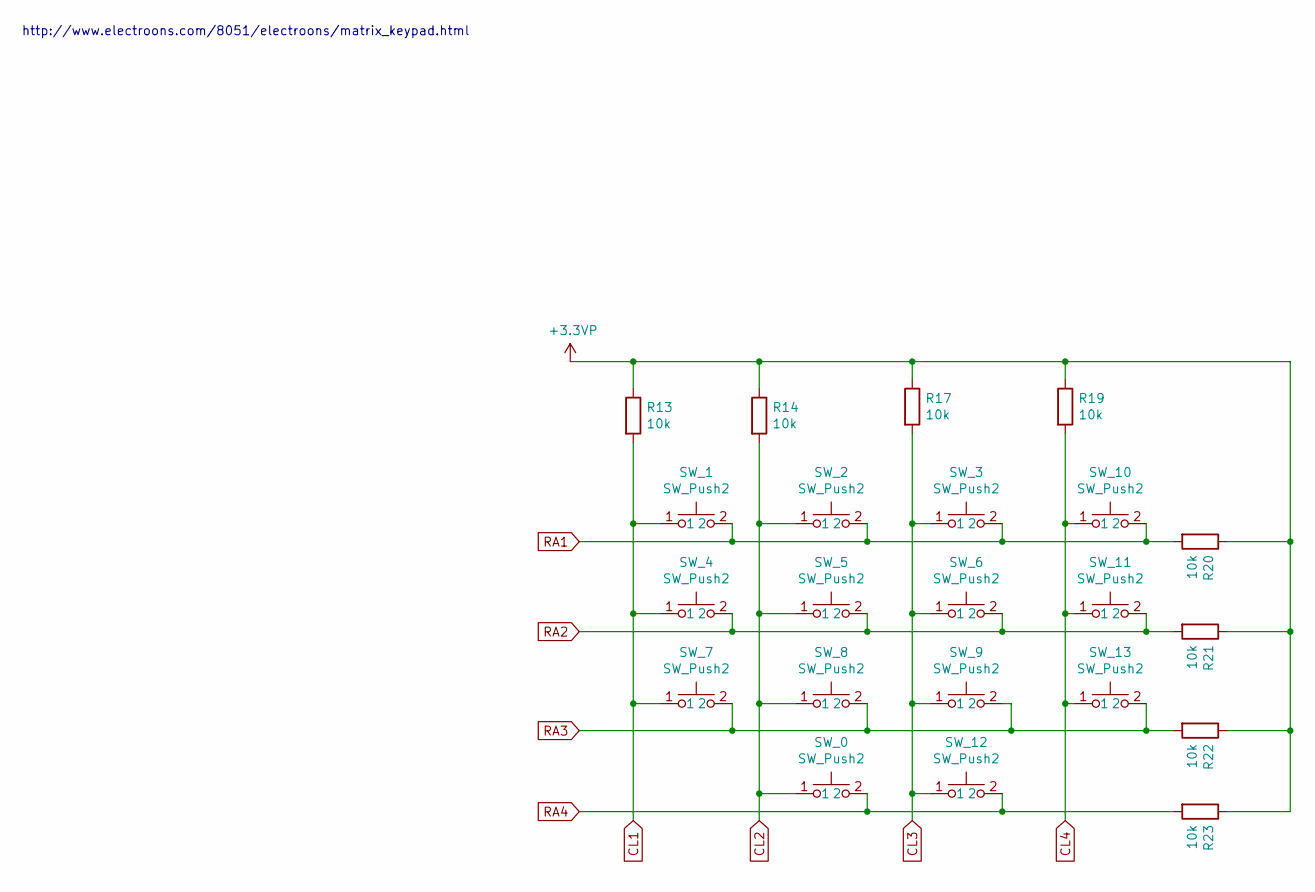
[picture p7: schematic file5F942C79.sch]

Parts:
R13, R14, R17, R19, R20, R21, R22, R23: 10k; R_0402_1005Metric
SW_0, SW_1, SW_2, SW_3, SW_4, SW_5, SW_6, SW_7, SW_8, SW_9, SW_10, SW_11, SW_12, SW_13: SW_Push2; Button_Test2

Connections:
+3.3VP: R13.1, R14.1, R17.1, R19.1, R20.1, R21.1, R22.1, R23.1; also elsewhere on the board
CL1: R13.2, SW_1.1, SW_4.1, SW_7.1; also elsewhere on the board
CL2: R14.2, SW_0.1, SW_2.1, SW_5.1, SW_8.1; also elsewhere on the board
CL3: R17.2, SW_3.1, SW_6.1, SW_9.1, SW_12.1; also elsewhere on the board
CL4: R19.2, SW_10.1, SW_11.1, SW_13.1; also elsewhere on the board
RA1: R20.2, SW_1.2, SW_2.2, SW_3.2, SW_10.2; also elsewhere on the board
RA2: R21.2, SW_4.2, SW_5.2, SW_6.2, SW_11.2; also elsewhere on the board
RA3: R22.2, SW_7.2, SW_8.2, SW_9.2, SW_13.2; also elsewhere on the board
RA4: R23.2, SW_0.2, SW_12.2; also elsewhere on the board

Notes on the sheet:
http://www.electroons.com/8051/electroons/matrix_keypad.html

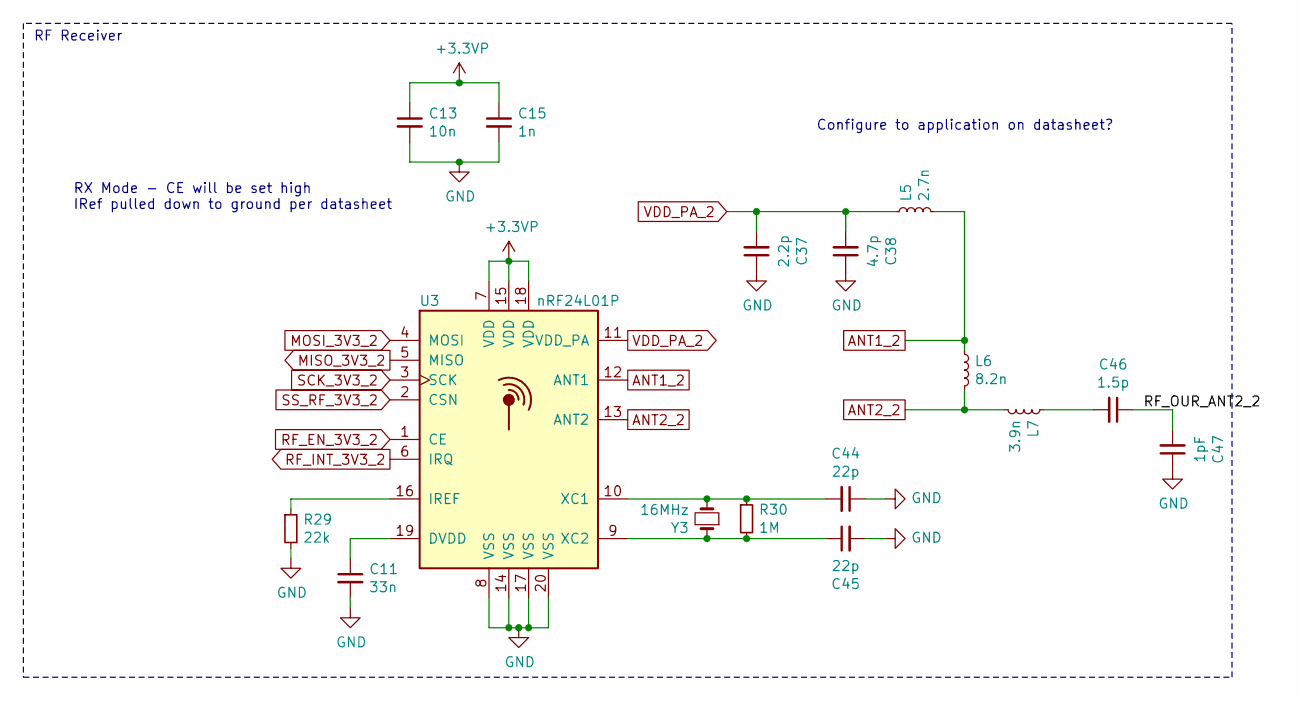
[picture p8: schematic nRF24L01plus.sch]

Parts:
C11: 33n; C_0402_1005Metric; Part Number 0402F333M500NT; LCSC Part # C1585
C13: 10n; C_0402_1005Metric; Part Number CL05B103KB5NNNC; LCSC Part # C15195
C15: 1n; C_0402_1005Metric; Part Number 0402B102K500NT; LCSC Part # C1523
C37: 2.2p; C_0402_1005Metric; Part Number 0402CG2R2C500NT; LCSC Part # C1559
C38: 4.7p; C_0402_1005Metric; Part Number 0402CG4R7C500NT; LCSC Part # C1569
C44, C45: 22p; C_0402_1005Metric; Part Number 0402CG220J500NT; LCSC Part # C1555
C46: 1.5p; C_0402_1005Metric; Part Number 0402CG1R5C500NT; LCSC Part # C1552
C47: 1pF; C_0402_1005Metric; Part Number 0402CG1R0C500NT; LCSC Part # C1550
L5: 2.7n; L_0402_1005Metric; Part Number SDCL1005C2N7STDF; LCSC Part # C27123
L6: 8.2n; L_0402_1005Metric; Part Number SDCL1005C8N2JTDF; LCSC Part # C16208
L7: 3.9n; L_0402_1005Metric; Part Number SDCL1005C3N9STDF; LCSC Part # C14033
R29: 22k; R_0402_1005Metric; Part Number 0402WGF2202TCE; LCSC Part # C25768
R30: 1M; R_0402_1005Metric; Part Number 0402WGF1004TCE; LCSC Part # C26083
U3: nRF24L01P; QFN-20-1EP_4x4mm_P0.5mm_EP2.5x2.5mm; Part Number NRF24L01P-R; LCSC Part # C8791
Y3: 16MHz; Crystal_HC49-4H_Vertical

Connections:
+3.3VP: C13.1, C15.1, U3.7 (VDD), U3.15 (VDD), U3.18 (VDD); also elsewhere on the board
/Trasmitter2/RF_OUR_ANT2_2: C46.1, C47.2
ANT1_2: L5.2, L6.1, U3.12 (ANT1)
ANT2_2: L6.2, L7.2, U3.13 (ANT2)
GND: C11.2, C13.2, C15.2, C37.1, C38.1, C44.1, C45.2, C47.1, R29.2, U3.8 (VSS), U3.14 (VSS), U3.17 (VSS), U3.20 (VSS); also elsewhere on the board
MISO_3V3_2: U3.5 (MISO); also elsewhere on the board
MOSI_3V3_2: U3.4 (MOSI); also elsewhere on the board
unnamed: C11.1, U3.19 (DVDD)
unnamed: C44.2, R30.1, U3.10 (XC1), Y3.2
unnamed: C45.1, R30.2, U3.9 (XC2), Y3.1
unnamed: C46.2, L7.1
unnamed: R29.1, U3.16 (IREF)
RF_EN_3V3_2: U3.1 (CE); also elsewhere on the board
RF_INT_3V3_2: U3.6 (IRQ); also elsewhere on the board
SCK_3V3_2: U3.3 (SCK); also elsewhere on the board
SS_RF_3V3_2: U3.2 (CSN); also elsewhere on the board
VDD_PA_2: C37.2, C38.2, L5.1, U3.11 (VDD_PA)

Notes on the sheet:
RX Mode - CE will be set high IRef pulled down to ground per datasheet
RF Receiver
Configure to application on datasheet?

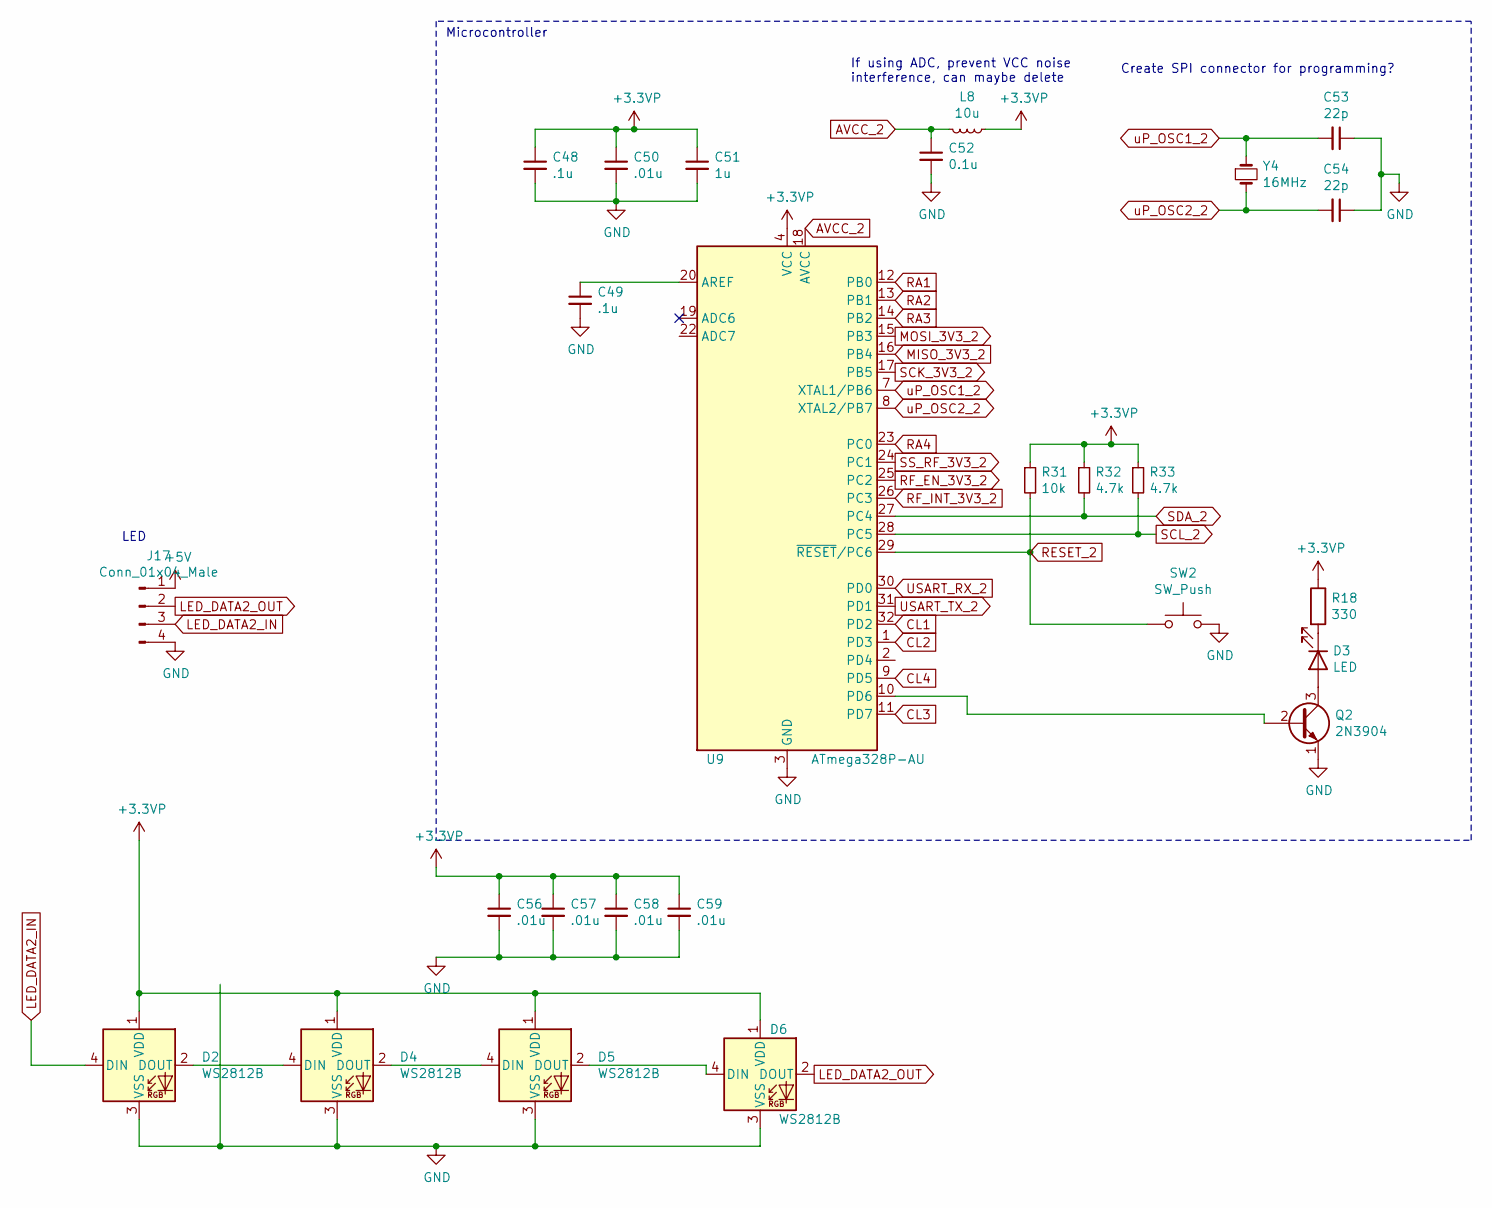
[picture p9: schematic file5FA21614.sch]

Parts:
C48, C49: .1u; C_0402_1005Metric; Part Number CL05B104KO5NNNC; LCSC Part # C1525
C50, C56, C57, C58, C59: .01u; C_0402_1005Metric; Part Number CL05B103KB5NNNC; LCSC Part # C15195
C51: 1u; C_0402_1005Metric; Part Number CL05A105KA5NQNC; LCSC Part # C52923
C52: 0.1u; C_0402_1005Metric; Part Number CL05B104KO5NNNC; LCSC Part # C1525
C53, C54: 22p; C_0402_1005Metric; Part Number 0402CG220J500NT; LCSC Part # C1555
D2, D4, D5, D6: WS2812B; LED_WS2812B_PLCC4_5.0x5.0mm_P3.2mm
D3: LED; LED_0603_1608Metric_Pad1.05x0.95mm_HandSolder
J17: Conn_01x04_Male; PinHeader_1x04_P2.54mm_Vertical
L8: 10u; L_0603_1608Metric_Pad1.05x0.95mm_HandSolder
Q2: 2N3904; SOT-23W_Handsoldering
R18: 330; R_0603_1608Metric_Pad1.05x0.95mm_HandSolder
R31: 10k; R_0402_1005Metric; Part Number 0402WGF1002TCE; LCSC Part # C25744
R32, R33: 4.7k; R_0402_1005Metric; Part Number 0402WGF4701TCE; LCSC Part # C25900
SW2: SW_Push; SW_PUSH_6mm_H5mm
U9: ATmega328P-AU; TQFP-32_7x7mm_P0.8mm; Part Number ATMEGA328P-AU; LCSC C14877
Y4: 16MHz; Crystal_HC49-4H_Vertical

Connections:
+3.3VP: C48.1, C50.1, C51.1, C56.1, C57.1, C58.1, C59.1, D2.1 (VDD), D4.1 (VDD), D5.1 (VDD), D6.1 (VDD), L8.1, R18.1, R31.1, R32.1, R33.1, U9.4 (VCC), U9.6 (VCC); also elsewhere on the board
AVCC_2: C52.1, L8.2, U9.18 (AVCC)
CL1: U9.32 (PD2); also elsewhere on the board
CL2: U9.1 (PD3); also elsewhere on the board
CL3: U9.11 (PD7); also elsewhere on the board
CL4: U9.9 (PD5); also elsewhere on the board
FAN_PWR: J17.1; also elsewhere on the board
GND: C48.2, C49.2, C50.2, C51.2, C52.2, C53.1, C54.1, C56.2, C57.2, C58.2, C59.2, D2.3 (VSS), D4.3 (VSS), D5.3 (VSS), D6.3 (VSS), J17.4, Q2.1 (E), SW2.2, U9.3 (GND), U9.5 (GND), U9.21 (GND); also elsewhere on the board
LED_DATA2_IN: D2.4 (DIN), J17.3
LED_DATA2_OUT: D6.2 (DOUT), J17.2
MISO_3V3_2: U9.16 (PB4); also elsewhere on the board
MOSI_3V3_2: U9.15 (PB3); also elsewhere on the board
unnamed: C49.1, U9.20 (AREF)
unnamed: D2.2 (DOUT), D4.4 (DIN)
unnamed: D3.1 (K), R18.2
unnamed: D3.2 (A), Q2.3 (C)
unnamed: D4.2 (DOUT), D5.4 (DIN)
unnamed: D5.2 (DOUT), D6.4 (DIN)
unnamed: Q2.2 (B), U9.10 (PD6)
RA1: U9.12 (PB0); also elsewhere on the board
RA2: U9.13 (PB1); also elsewhere on the board
RA3: U9.14 (PB2); also elsewhere on the board
RA4: U9.23 (PC0); also elsewhere on the board
RESET_2: R31.2, SW2.1, U9.29 (~RESET~/PC6); also elsewhere on the board
RF_EN_3V3_2: U9.25 (PC2); also elsewhere on the board
RF_INT_3V3_2: U9.26 (PC3); also elsewhere on the board
SCK_3V3_2: U9.17 (PB5); also elsewhere on the board
SCL_2: R33.2, U9.28 (PC5)
SDA_2: R32.2, U9.27 (PC4)
SS_RF_3V3_2: U9.24 (PC1); also elsewhere on the board
USART_RX_2: U9.30 (PD0)
USART_TX_2: U9.31 (PD1)
uP_OSC1_2: C53.2, U9.7 (XTAL1/PB6), Y4.1
uP_OSC2_2: C54.2, U9.8 (XTAL2/PB7), Y4.2

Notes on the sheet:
If using ADC, prevent VCC noise interference, can maybe delete
Create SPI connector for programming?
Microcontroller
LED

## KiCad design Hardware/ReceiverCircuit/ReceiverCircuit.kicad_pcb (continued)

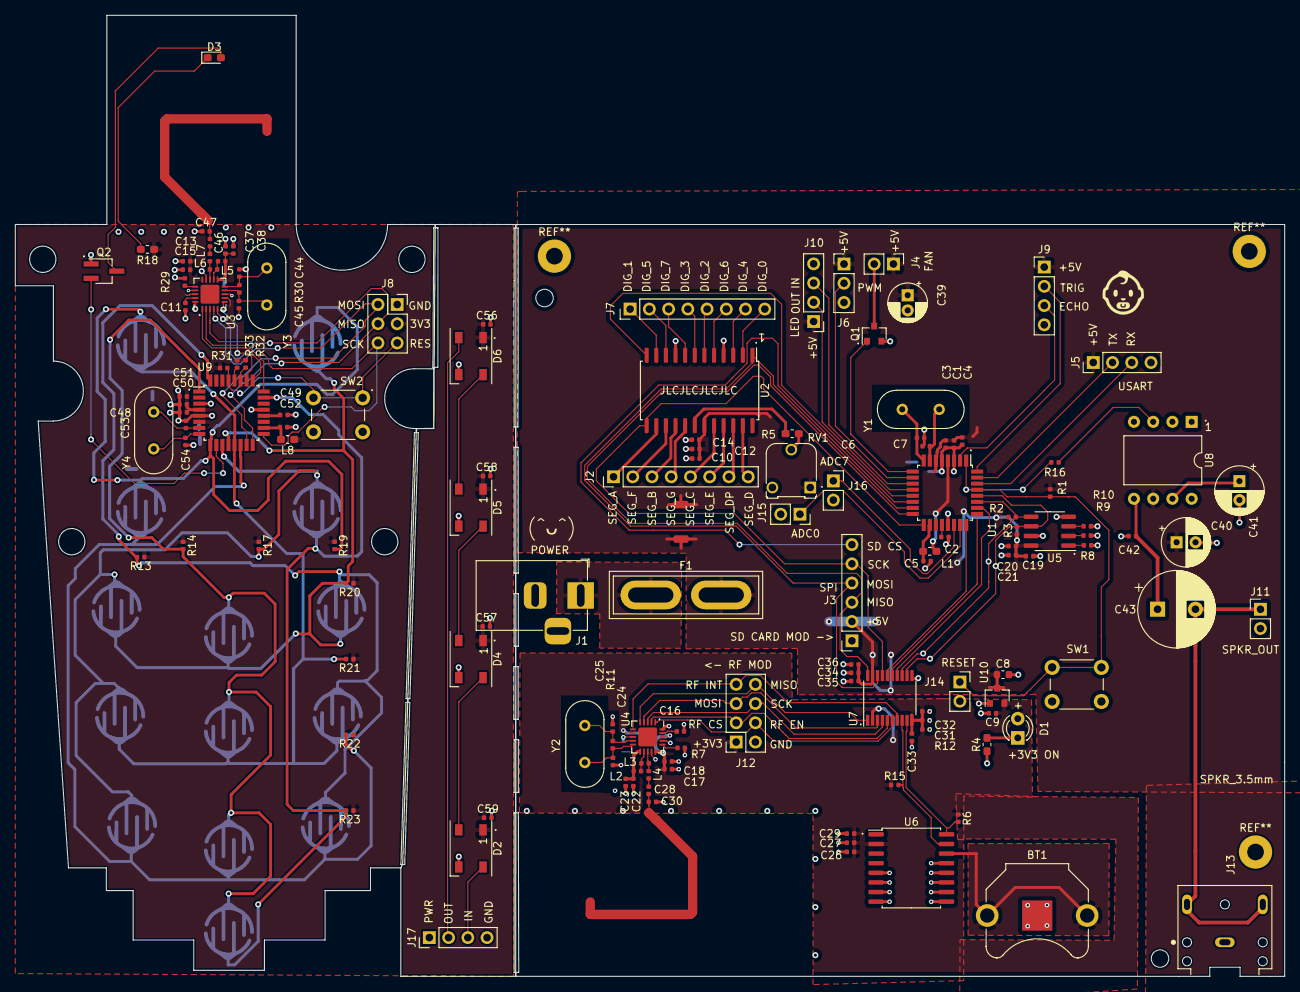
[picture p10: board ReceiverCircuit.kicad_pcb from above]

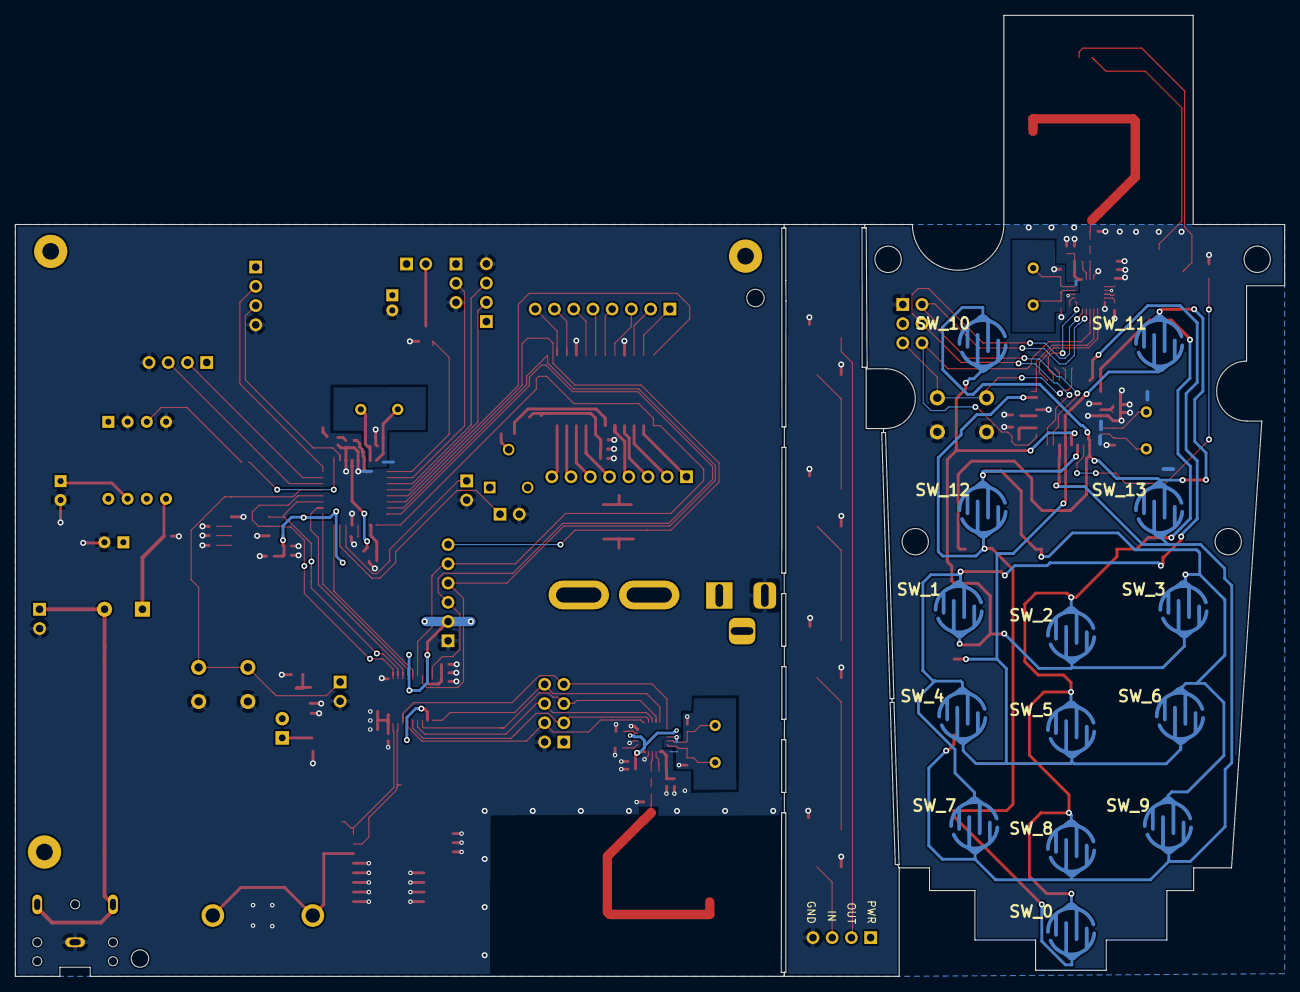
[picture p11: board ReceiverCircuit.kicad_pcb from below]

Board: 2 copper layers, 167.6 x 126.9 mm, 152 parts (14 on the bottom side), 114 nets.

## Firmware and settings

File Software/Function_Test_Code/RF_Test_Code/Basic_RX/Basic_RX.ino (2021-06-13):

<<<<<<< HEAD
/*

Demonstrates simple RX and TX operation.
Any of the Basic_TX examples can be used as a transmitter.
Please read through 'NRFLite.h' for a description of all the methods available in the library.

Radio    Arduino
CE    -> 9 (for uno), 16 (for unit)
CSN   -> 10 (Hardware SPI SS) (for uno), 15 (for unit)
MOSI  -> 11 (Hardware SPI MOSI)
MISO  -> 12 (Hardware SPI MISO)
SCK   -> 13 (Hardware SPI SCK)
IRQ   -> No connection
VCC   -> No more than 3.6 volts
GND   -> GND

*/

#include <SPI.h>
#include <NRFLite.h>

const static uint8_t RADIO_ID = 0;       // Our radio's id.  The transmitter will send to this id.
const static uint8_t PIN_RADIO_CE = 16;
const static uint8_t PIN_RADIO_CSN = 15;

struct RadioPacket // Any packet up to 32 bytes can be sent.
{
    uint8_t FromRadioId;
    uint32_t OnTimeMillis;
    uint32_t FailedTxCount;
    uint8_t PlaySong;
};

NRFLite _radio;
RadioPacket _radioData;

void setup()
{
    Serial.begin(115200);

    // By default, 'init' configures the radio to use a 2MBPS bitrate on channel 100 (channels 0-125 are valid).
    // Both the RX and TX radios must have the same bitrate and channel to communicate with each other.
    // You can run the 'ChannelScanner' example to help select the best channel for your environment.
    // You can assign a different bitrate and channel as shown below.
    //   _radio.init(RADIO_ID, PIN_RADIO_CE, PIN_RADIO_CSN, NRFLite::BITRATE2MBPS, 100) // THE DEFAULT
    //   _radio.init(RADIO_ID, PIN_RADIO_CE, PIN_RADIO_CSN, NRFLite::BITRATE1MBPS, 75)
    //   _radio.init(RADIO_ID, PIN_RADIO_CE, PIN_RADIO_CSN, NRFLite::BITRATE250KBPS, 0)
//    pinMode(10, OUTPUT); 
//    pinMode(15, OUTPUT);
//    digitalWrite(10, HIGH);
//    digitalWrite(15, HIGH);
//
//    SPI.begin();
    
    if (!_radio.init(RADIO_ID, PIN_RADIO_CE, PIN_RADIO_CSN))
    {
        Serial.println("Cannot communicate with radio");
        while (1); // Wait here forever.
    }
//    Serial.println("I think we can communicat"); 
}

void loop()
{
//    Serial.println("We're in the loop");
//    if (!_radio.init(RADIO_ID, PIN_RADIO_CE, PIN_RADIO_CSN))
//      {
//          Serial.println("Cannot communicate with radio");
////          while (1); // Wait here forever.
//      }
    while (_radio.hasData())
    {
        //Serial.print("radio has data "); 
        _radio.readData(&_radioData); // Note how '&' must be placed in front of the variable name.

        String msg = "Radio ";
        msg += _radioData.FromRadioId;
        msg += ", ";
        msg += _radioData.OnTimeMillis;
        msg += " ms, ";                                                                                                    
        msg += _radioData.FailedTxCount;
        msg += " Failed TX";
        msg += " Play Song is";
        msg += _radioData.PlaySong;

        Serial.println(msg);
    }
    delay(1000);
}
=======
/*

Demonstrates simple RX and TX operation.
Any of the Basic_TX examples can be used as a transmitter.
Please read through 'NRFLite.h' for a description of all the methods available in the library.

Radio    Arduino
CE    -> 9
CSN   -> 10 (Hardware SPI SS)
MOSI  -> 11 (Hardware SPI MOSI)
MISO  -> 12 (Hardware SPI MISO)
SCK   -> 13 (Hardware SPI SCK)
IRQ   -> No connection
VCC   -> No more than 3.6 volts
GND   -> GND

*/

#include <SPI.h>
#include <NRFLite.h>


#include <Adafruit_NeoPixel.h>
#ifdef __AVR__
 #include <avr/power.h> // Required for 16 MHz Adafruit Trinket
#endif


#define PIN   8
#define NUMPIXELS 4 // Popular NeoPixel ring size


Adafruit_NeoPixel pixels(NUMPIXELS, PIN, NEO_GRB + NEO_KHZ800);

#define DELAYVAL 500 // Time (in milliseconds) to pause between pixels
#define intensity 50
const static uint8_t RADIO_ID = 0;       // Our radio's id.  The transmitter will send to this id.
const static uint8_t PIN_RADIO_CE = 16;
const static uint8_t PIN_RADIO_CSN = 15;

struct RadioPacket // Any packet up to 32 bytes can be sent.
{
    uint8_t LED0;
    uint8_t LED1;
    uint8_t LED2;
    uint8_t LED3;
    uint8_t FAN;
};
char LED0,LED1,LED2,LED3;

NRFLite _radio;
RadioPacket _radioData;

void setup()
{

  #if defined(__AVR_ATtiny85__) && (F_CPU == 16000000)
  clock_prescale_set(clock_div_1);
#endif
  // END of Trinket-specific code.

  pixels.begin(); // INITIALIZE NeoPixel strip object (REQUIRED)
    Serial.begin(9600);

    // By default, 'init' configures the radio to use a 2MBPS bitrate on channel 100 (channels 0-125 are valid).
    // Both the RX and TX radios must have the same bitrate and channel to communicate with each other.
    // You can run the 'ChannelScanner' example to help select the best channel for your environment.
    // You can assign a different bitrate and channel as shown below.
    //   _radio.init(RADIO_ID, PIN_RADIO_CE, PIN_RADIO_CSN, NRFLite::BITRATE2MBPS, 100) // THE DEFAULT
    //   _radio.init(RADIO_ID, PIN_RADIO_CE, PIN_RADIO_CSN, NRFLite::BITRATE1MBPS, 75)
    //   _radio.init(RADIO_ID, PIN_RADIO_CE, PIN_RADIO_CSN, NRFLite::BITRATE250KBPS, 0)
    
    if (!_radio.init(RADIO_ID, PIN_RADIO_CE, PIN_RADIO_CSN))
    {
     //   Serial.println("Cannot communicate with radio");
        while (1); // Wait here forever.
    }
  pinMode(5, OUTPUT);
    
}

void loop()
{
    while (_radio.hasData())
    {
        _radio.readData(&_radioData); // Note how '&' must be placed in front of the variable name.

      String msg = "Recieved: ";
        msg += _radioData.LED0;
        //msg +=  _radioData.LED1;
        //msg +=  _radioData.LED2;
        //msg +=  _radioData.LED3;
      //int LED0 = _radioData.LED0;
      Serial.print("A");
       Serial.print(_radioData.LED0);
       Serial.print(_radioData.LED1);
       Serial.print(_radioData.LED2);
       Serial.print(_radioData.FAN);
pixels.clear(); // Set all pixel colors to 'off'


LED_CTRL(_radioData.LED0,0);
LED_CTRL(_radioData.LED1,1);
LED_CTRL(_radioData.LED2,2);
LED_CTRL(_radioData.LED3,3);

 analogWrite(5,100);   // turn the LED on (HIGH is the voltage level)
                     // wait for a second

    }
}
    uint8_t LED_CTRL (uint8_t LEDX, char num){
        switch (LEDX){
          case 1:
           pixels.setPixelColor(num, pixels.Color(0, 0, intensity));
           pixels.show();   // Send the updated pixel colors to the hardware.
           break;
          case 2:
           pixels.setPixelColor(num, pixels.Color(0, intensity, 0));
           pixels.show();   // Send the updated pixel colors to the hardware.
           break;
          case 3:
           pixels.setPixelColor(num, pixels.Color(0, intensity, intensity));
           pixels.show();   // Send the updated pixel colors to the hardware.
           break;
          case 4:
           pixels.setPixelColor(num, pixels.Color(intensity, 0, 0));
           pixels.show();   // Send the updated pixel colors to the hardware.
           break;
          case 5:
           pixels.setPixelColor(num, pixels.Color(intensity, 0, intensity));
           pixels.show();   // Send the updated pixel colors to the hardware.
           break;
          case 6:
           pixels.setPixelColor(num, pixels.Color(intensity, intensity, 0));
           pixels.show();   // Send the updated pixel colors to the hardware.
           break;
          case 7:
           pixels.setPixelColor(num, pixels.Color(intensity, intensity, intensity));
           pixels.show();   // Send the updated pixel colors to the hardware.
           break;
          default:
           pixels.clear();
           break;
        }
      
    }
>>>>>>> ce5a902053183234d1600abe7bf83e4eb2666f43

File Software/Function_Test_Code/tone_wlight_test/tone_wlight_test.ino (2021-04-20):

#include "notes.h"
//#include "test.h"
#include <Arduino.h>
#include <Adafruit_NeoPixel.h>




// int marioMelody[] 

// NeoPixel Ring simple sketch (c) 2013 Shae Erisson
// Released under the GPLv3 license to match the rest of the
// Adafruit NeoPixel library

#ifdef __AVR__
 #include <avr/power.h> // Required for 16 MHz Adafruit Trinket
#endif

// Which pin on the Arduino is connected to the NeoPixels?
#define PIN        8 // On Trinket or Gemma, suggest changing this to 1

// How many NeoPixels are attached to the Arduino?
#define NUMPIXELS 4 // Popular NeoPixel ring size

// When setting up the NeoPixel library, we tell it how many pixels,
// and which pin to use to send signals. Note that for older NeoPixel
// strips you might need to change the third parameter -- see the
// strandtest example for more information on possible values.
Adafruit_NeoPixel pixels(NUMPIXELS, PIN, NEO_GRB + NEO_KHZ800);

#define DELAYVAL 500 // Time (in milliseconds) to pause between pixels

    int marioMelody[] = { NOTE_E5,8, NOTE_E5,8, REST,8, NOTE_E5,8, REST,8, NOTE_C5,8, NOTE_E5,8, //1
        NOTE_G5,4, REST,4, NOTE_G4,8, REST,4, 
        NOTE_C5,-4, NOTE_G4,8, REST,4, NOTE_E4,-4, // 3
        NOTE_A4,4, NOTE_B4,4, NOTE_AS4,8, NOTE_A4,4,
        NOTE_G4,-8, NOTE_E5,-8, NOTE_G5,-8, NOTE_A5,4, NOTE_F5,8, NOTE_G5,8,
        REST,8, NOTE_E5,4,NOTE_C5,8, NOTE_D5,8, NOTE_B4,-4,
        NOTE_C5,-4, NOTE_G4,8, REST,4, NOTE_E4,-4, // repeats from 3
        NOTE_A4,4, NOTE_B4,4, NOTE_AS4,8, NOTE_A4,4,
        NOTE_G4,-8, NOTE_E5,-8, NOTE_G5,-8, NOTE_A5,4, NOTE_F5,8, NOTE_G5,8,
        REST,8, NOTE_E5,4,NOTE_C5,8, NOTE_D5,8, NOTE_B4,-4,
      
        
        REST,4, NOTE_G5,8, NOTE_FS5,8, NOTE_F5,8, NOTE_DS5,4, NOTE_E5,8,//7
        REST,8, NOTE_GS4,8, NOTE_A4,8, NOTE_C4,8, REST,8, NOTE_A4,8, NOTE_C5,8, NOTE_D5,8,
        REST,4, NOTE_DS5,4, REST,8, NOTE_D5,-4,
        NOTE_C5,2, REST,2,
      
        REST,4, NOTE_G5,8, NOTE_FS5,8, NOTE_F5,8, NOTE_DS5,4, NOTE_E5,8,//repeats from 7
        REST,8, NOTE_GS4,8, NOTE_A4,8, NOTE_C4,8, REST,8, NOTE_A4,8, NOTE_C5,8, NOTE_D5,8,
        REST,4, NOTE_DS5,4, REST,8, NOTE_D5,-4,
        NOTE_C5,2, REST,2,
      
        NOTE_C5,8, NOTE_C5,4, NOTE_C5,8, REST,8, NOTE_C5,8, NOTE_D5,4,//11
        NOTE_E5,8, NOTE_C5,4, NOTE_A4,8, NOTE_G4,2,
      
        NOTE_C5,8, NOTE_C5,4, NOTE_C5,8, REST,8, NOTE_C5,8, NOTE_D5,8, NOTE_E5,8,//13
        REST,1, 
        NOTE_C5,8, NOTE_C5,4, NOTE_C5,8, REST,8, NOTE_C5,8, NOTE_D5,4,
        NOTE_E5,8, NOTE_C5,4, NOTE_A4,8, NOTE_G4,2,
        NOTE_E5,8, NOTE_E5,8, REST,8, NOTE_E5,8, REST,8, NOTE_C5,8, NOTE_E5,4,
        NOTE_G5,4, REST,4, NOTE_G4,4, REST,4, 
        NOTE_C5,-4, NOTE_G4,8, REST,4, NOTE_E4,-4, // 19
        
        NOTE_A4,4, NOTE_B4,4, NOTE_AS4,8, NOTE_A4,4,
        NOTE_G4,-8, NOTE_E5,-8, NOTE_G5,-8, NOTE_A5,4, NOTE_F5,8, NOTE_G5,8,
        REST,8, NOTE_E5,4, NOTE_C5,8, NOTE_D5,8, NOTE_B4,-4,
      
        NOTE_C5,-4, NOTE_G4,8, REST,4, NOTE_E4,-4, // repeats from 19
        NOTE_A4,4, NOTE_B4,4, NOTE_AS4,8, NOTE_A4,4,
        NOTE_G4,-8, NOTE_E5,-8, NOTE_G5,-8, NOTE_A5,4, NOTE_F5,8, NOTE_G5,8,
        REST,8, NOTE_E5,4, NOTE_C5,8, NOTE_D5,8, NOTE_B4,-4,
      
        NOTE_E5,8, NOTE_C5,4, NOTE_G4,8, REST,4, NOTE_GS4,4,//23
        NOTE_A4,8, NOTE_F5,4, NOTE_F5,8, NOTE_A4,2,
        NOTE_D5,-8, NOTE_A5,-8, NOTE_A5,-8, NOTE_A5,-8, NOTE_G5,-8, NOTE_F5,-8,
        
        NOTE_E5,8, NOTE_C5,4, NOTE_A4,8, NOTE_G4,2, //26
        NOTE_E5,8, NOTE_C5,4, NOTE_G4,8, REST,4, NOTE_GS4,4,
        NOTE_A4,8, NOTE_F5,4, NOTE_F5,8, NOTE_A4,2,
        NOTE_B4,8, NOTE_F5,4, NOTE_F5,8, NOTE_F5,-8, NOTE_E5,-8, NOTE_D5,-8,
        NOTE_C5,8, NOTE_E4,4, NOTE_E4,8, NOTE_C4,2,
      
        NOTE_E5,8, NOTE_C5,4, NOTE_G4,8, REST,4, NOTE_GS4,4,//repeats from 23
        NOTE_A4,8, NOTE_F5,4, NOTE_F5,8, NOTE_A4,2,
        NOTE_D5,-8, NOTE_A5,-8, NOTE_A5,-8, NOTE_A5,-8, NOTE_G5,-8, NOTE_F5,-8,
        
        NOTE_E5,8, NOTE_C5,4, NOTE_A4,8, NOTE_G4,2, //26
        NOTE_E5,8, NOTE_C5,4, NOTE_G4,8, REST,4, NOTE_GS4,4,
        NOTE_A4,8, NOTE_F5,4, NOTE_F5,8, NOTE_A4,2,
        NOTE_B4,8, NOTE_F5,4, NOTE_F5,8, NOTE_F5,-8, NOTE_E5,-8, NOTE_D5,-8,
        NOTE_C5,8, NOTE_E4,4, NOTE_E4,8, NOTE_C4,2,
        NOTE_C5,8, NOTE_C5,4, NOTE_C5,8, REST,8, NOTE_C5,8, NOTE_D5,8, NOTE_E5,8,
        REST,1,
      
        NOTE_C5,8, NOTE_C5,4, NOTE_C5,8, REST,8, NOTE_C5,8, NOTE_D5,4, //33
        NOTE_E5,8, NOTE_C5,4, NOTE_A4,8, NOTE_G4,2,
        NOTE_E5,8, NOTE_E5,8, REST,8, NOTE_E5,8, REST,8, NOTE_C5,8, NOTE_E5,4,
        NOTE_G5,4, REST,4, NOTE_G4,4, REST,4, 
        NOTE_E5,8, NOTE_C5,4, NOTE_G4,8, REST,4, NOTE_GS4,4,
        NOTE_A4,8, NOTE_F5,4, NOTE_F5,8, NOTE_A4,2,
        NOTE_D5,-8, NOTE_A5,-8, NOTE_A5,-8, NOTE_A5,-8, NOTE_G5,-8, NOTE_F5,-8,
        
        NOTE_E5,8, NOTE_C5,4, NOTE_A4,8, NOTE_G4,2, //40
        NOTE_E5,8, NOTE_C5,4, NOTE_G4,8, REST,4, NOTE_GS4,4,
        NOTE_A4,8, NOTE_F5,4, NOTE_F5,8, NOTE_A4,2,
        NOTE_B4,8, NOTE_F5,4, NOTE_F5,8, NOTE_F5,-8, NOTE_E5,-8, NOTE_D5,-8,
        NOTE_C5,8, NOTE_E4,4, NOTE_E4,8, NOTE_C4,2,
        
        //game over sound
        NOTE_C5,-4, NOTE_G4,-4, NOTE_E4,4, //45
        NOTE_A4,-8, NOTE_B4,-8, NOTE_A4,-8, NOTE_GS4,-8, NOTE_AS4,-8, NOTE_GS4,-8,
        NOTE_G4,8, NOTE_D4,8, NOTE_E4,-2,  
    
      };

      int starwarsMelody[] = {
  
        // Dart Vader theme (Imperial March) - Star wars 
        // Score available at https://musescore.com/user/202909/scores/1141521
        // The tenor saxophone part was used
        
        NOTE_AS4,8, NOTE_AS4,8, NOTE_AS4,8,//1, 7 elem
        NOTE_F5,2, NOTE_C6,2, // 4 elem
        NOTE_AS5,8, NOTE_A5,8, NOTE_G5,8, NOTE_F6,2, NOTE_C6,4,  // 10 elem
        NOTE_AS5,8, NOTE_A5,8, NOTE_G5,8, NOTE_F6,2, NOTE_C6,4,  // 10 elem
        NOTE_AS5,8, NOTE_A5,8, NOTE_AS5,8, NOTE_G5,2, NOTE_C5,8, NOTE_C5,8, NOTE_C5,8, // 14 elem
        NOTE_F5,2, NOTE_C6,2, // 4 elem
        NOTE_AS5,8, NOTE_A5,8, NOTE_G5,8, NOTE_F6,2, NOTE_C6,4,  // 10 elem
        
        NOTE_AS5,8, NOTE_A5,8, NOTE_G5,8, NOTE_F6,2, NOTE_C6,4, //8  10 elem
        NOTE_AS5,8, NOTE_A5,8, NOTE_AS5,8, NOTE_G5,2, NOTE_C5,-8, NOTE_C5,16, // 12 elem
        NOTE_D5,-4, NOTE_D5,8, NOTE_AS5,8, NOTE_A5,8, NOTE_G5,8, NOTE_F5,8, // 12 elem
        NOTE_F5,8, NOTE_G5,8, NOTE_A5,8, NOTE_G5,4, NOTE_D5,8, NOTE_E5,4,NOTE_C5,-8, NOTE_C5,16, // 16 elem
        NOTE_D5,-4, NOTE_D5,8, NOTE_AS5,8, NOTE_A5,8, NOTE_G5,8, NOTE_F5,8, // 12 elem
        
        NOTE_C6,-8, NOTE_G5,16, NOTE_G5,2, REST,8, NOTE_C5,8,//13 5 elem
        NOTE_D5,-4, NOTE_D5,8, NOTE_AS5,8, NOTE_A5,8, NOTE_G5,8, NOTE_F5,8, // 6 elem
        NOTE_F5,8, NOTE_G5,8, NOTE_A5,8, NOTE_G5,4, NOTE_D5,8, NOTE_E5,4,NOTE_C6,-8, NOTE_C6,16, // 8 elem
        NOTE_F6,4, NOTE_DS6,8, NOTE_CS6,4, NOTE_C6,8, NOTE_AS5,4, NOTE_GS5,8, NOTE_G5,4, NOTE_F5,8, // 8 elem
        NOTE_C6,1 // 2 elem
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

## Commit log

2021-02-18 Added tone melody test code
    Test code is modified for use on the unit board
2021-02-20 Add Wireless Toy Project Structure
2021-03-05 Add files via upload
    Initial code to test button array functionality.
2021-06-05 Add files via upload
    TX has code to support LED control at RX
2021-06-13 Added PCB Files
    [Circuit-BOM.csv, ReceiverCircuit-BOM.csv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]
2021-11-23 Added PCB img
